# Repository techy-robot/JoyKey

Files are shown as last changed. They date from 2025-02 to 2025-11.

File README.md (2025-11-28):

---
modified: 2025-02-20T21:09:22-07:00
---
# JoyKey
This is a small macropad that simultaneously acts as game controller and an entertainment device. 

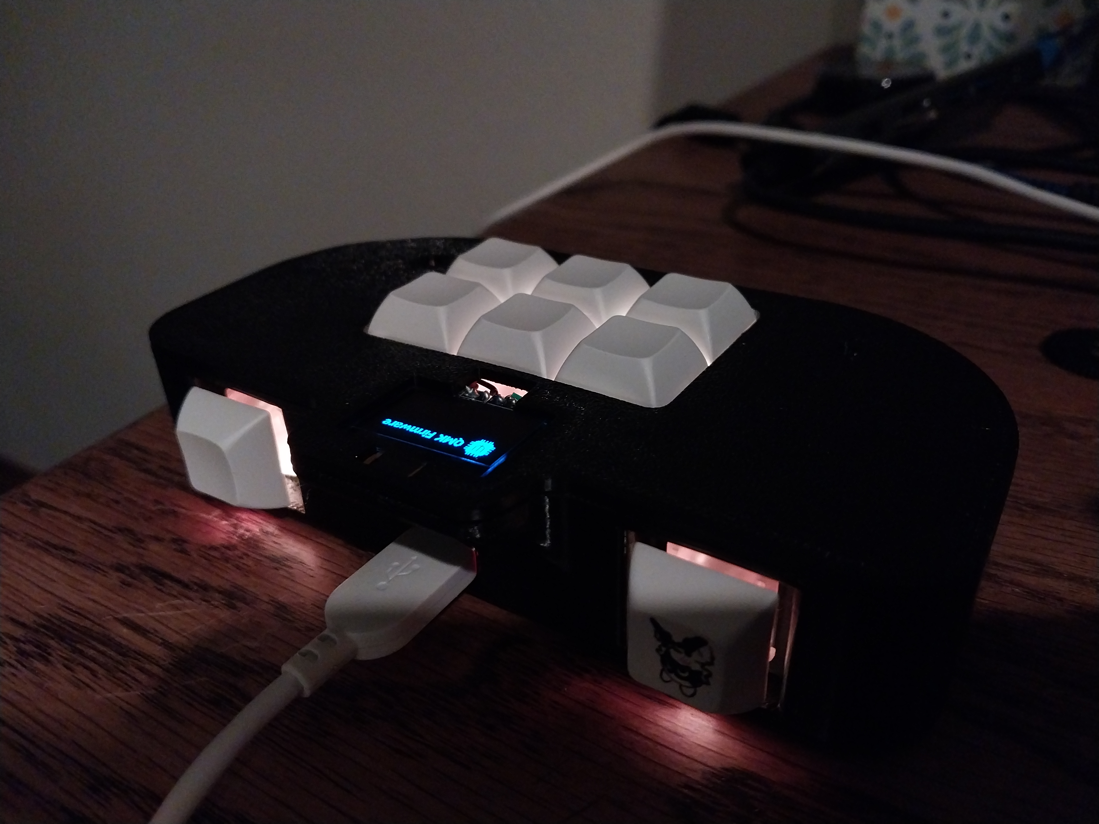
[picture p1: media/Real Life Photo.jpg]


The name is inspired by the Nintendo JoyCon portmanteau (Joystick Controller) except I have replaced the 2nd word with "Keypad" (Joystick Keypad). See [name ideas](name%20ideas.md) for other things I came up with.

My main repo were development will continue: https://github.com/techy-robot/JoyKey

# Features
- Customizable macro pad using QMK firmware
- Game controller mimicking a joy-con
- Offline games that can be played on the display with no connections
- Small handheld size
- Linear keys

# Approoved Parts BOM
- 8 Cherry mx Red keys with clear shell variant
- 8 Black keycaps
- 128x64 px SSD1306-based monochrome display near the top
- SEEED Xiao RP2040 (can be replaced later w/ SEEED xiao MG24 or nRF52840 Sense for BLE and other goodies)
- 12 Sk6812 Mini-E reverse mount RGB leds
- 3 M3x16 screws and M3 heatsets

# Extra Parts BOM
- 1 Analog PS2 Joystick (I already have)
- 1 Alps SRBE110301. (flat volume dial on the side). LCSC #C160861
- AP2112K-3.3 Linear Regulator. LCSC #C51118
- MCP73831T-2ACI/OT Lipo Battery Charger. LCSC #C424093
- 4 10uf 0805 capacitors. LCSC #C15850
- DMG3415 Sot23-3 PMOS. LCSC #C7202986
- 3 10k 0805 resistors. LCSC #C17414
- 1 2k 0805 resistor. LCSC #C17604
- 1 0603 LED. LCSC #C2286
- 1 LSM6DS3 LCSC #C967633
- JST PH S2B smd LCSC #C295747
- 12 1N4148W diodes LCSC #C2128
- 1 MBR0540 schotkey LCSC #C78545

# Pictures

## Case
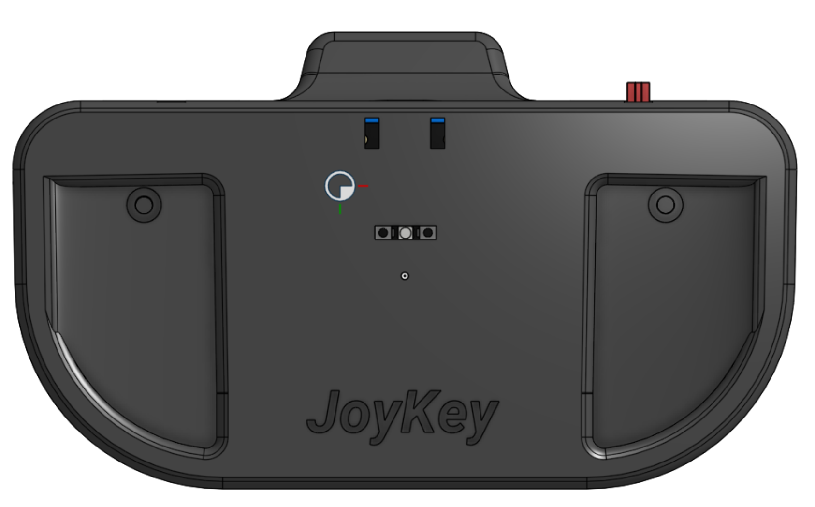
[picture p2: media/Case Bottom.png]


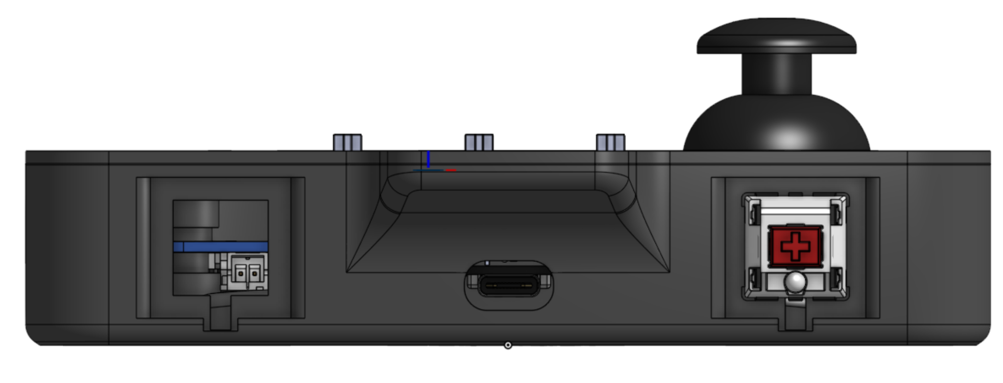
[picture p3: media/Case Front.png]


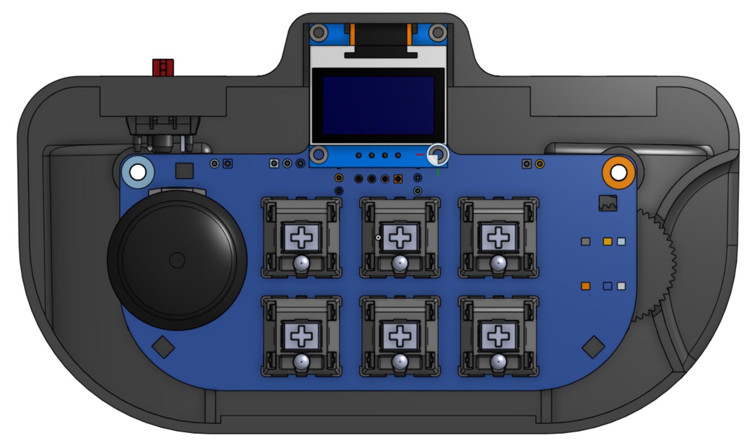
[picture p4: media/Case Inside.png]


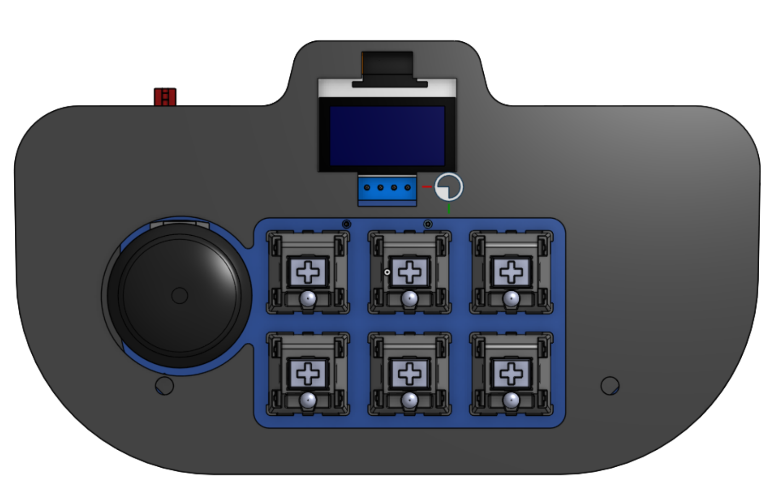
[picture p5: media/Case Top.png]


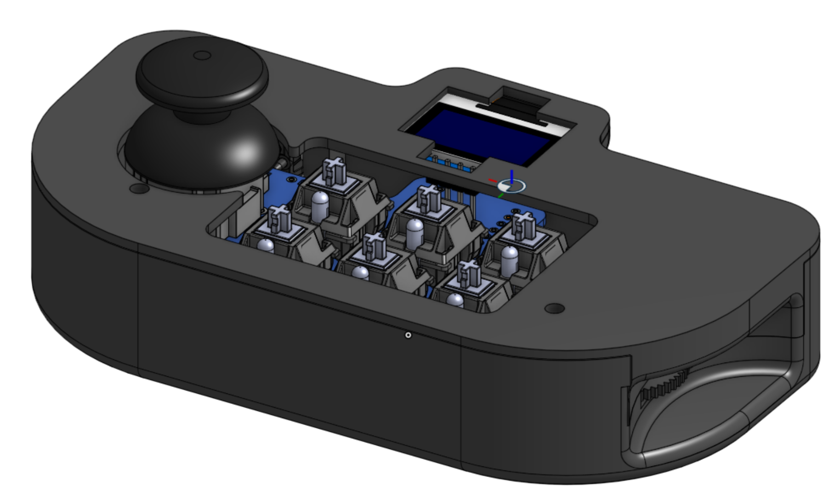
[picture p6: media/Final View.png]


## PCB
Bottom
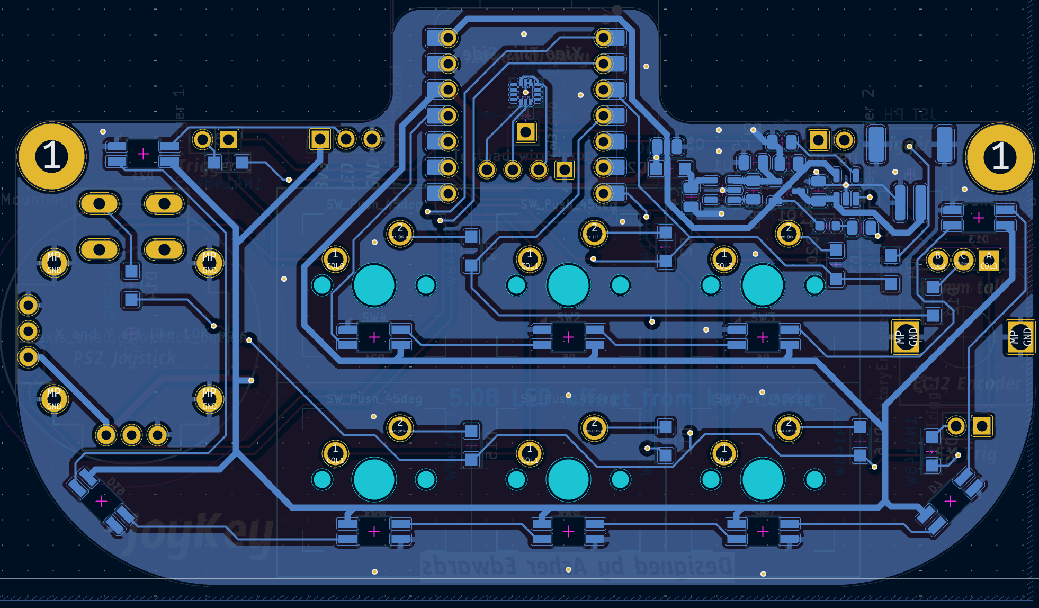
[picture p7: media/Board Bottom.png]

Top
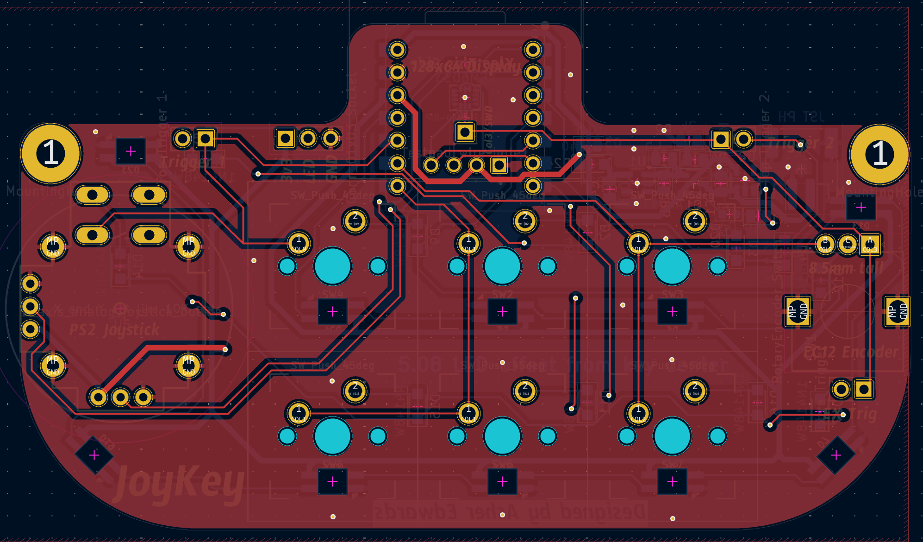
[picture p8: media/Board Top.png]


## Schematic
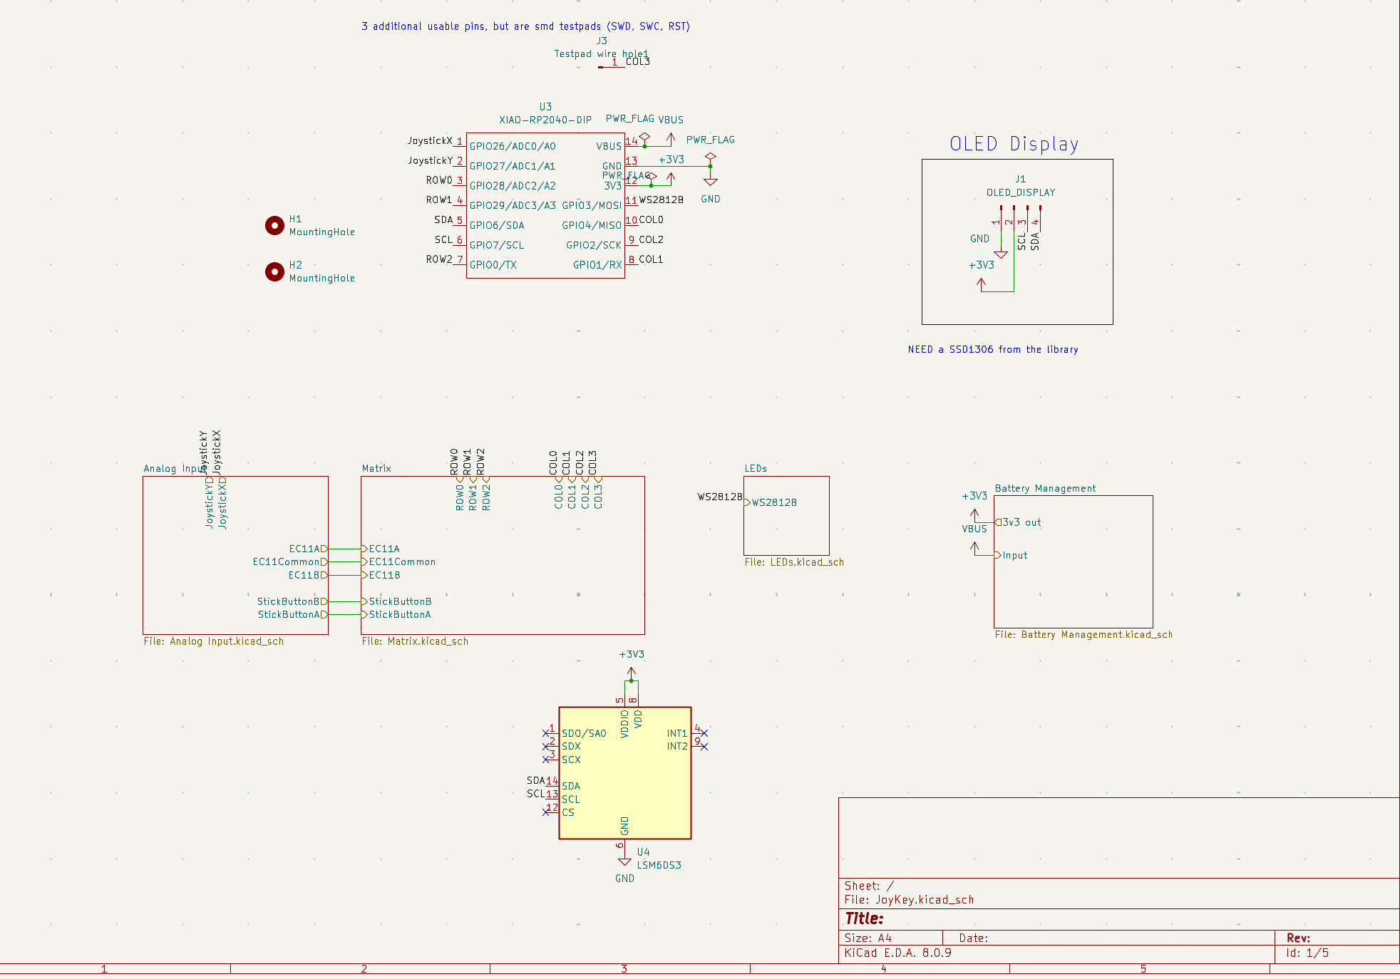
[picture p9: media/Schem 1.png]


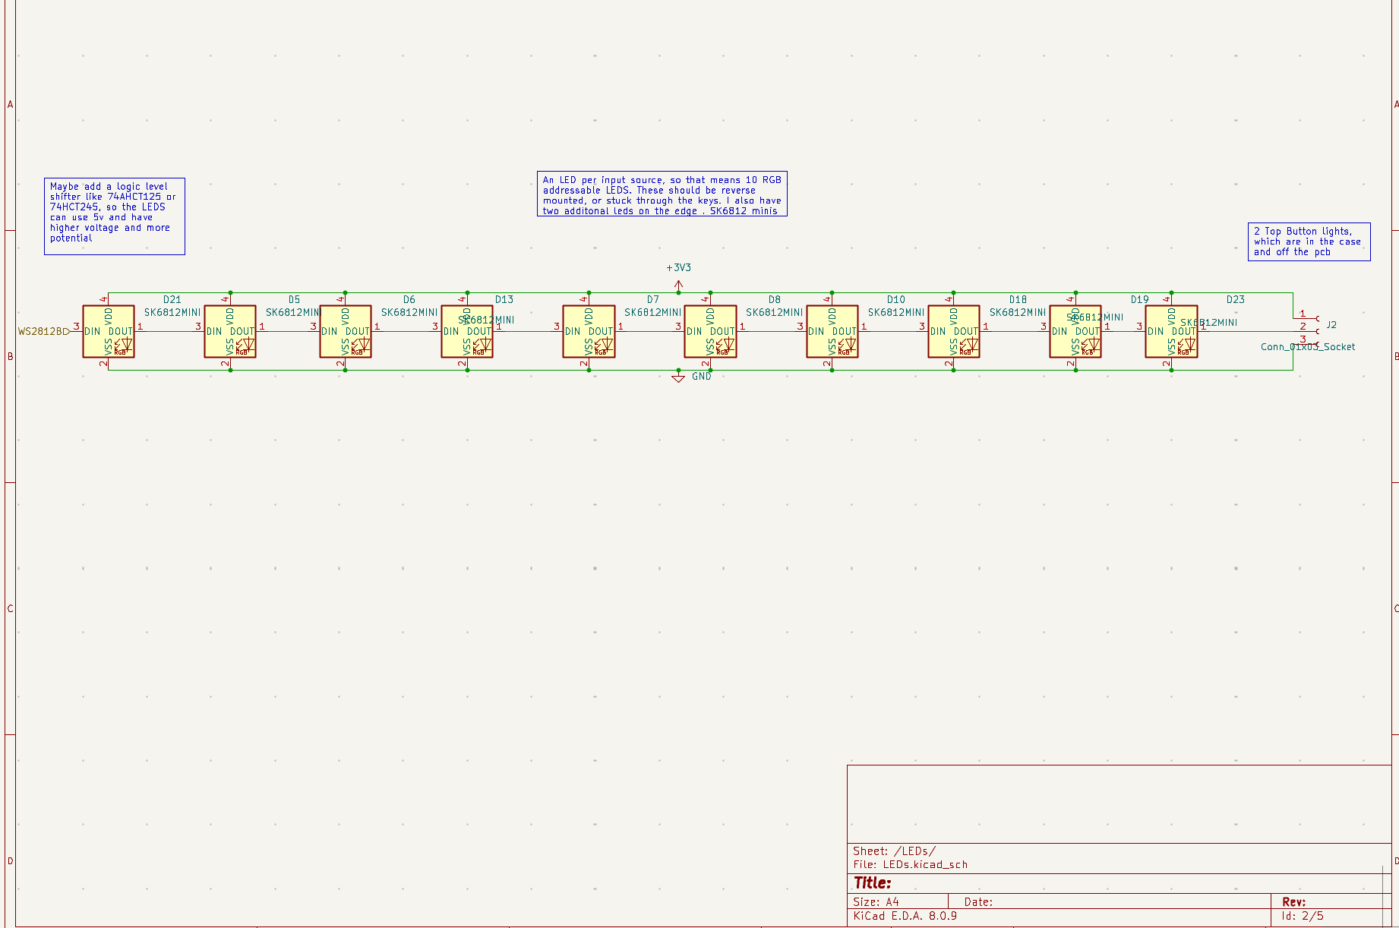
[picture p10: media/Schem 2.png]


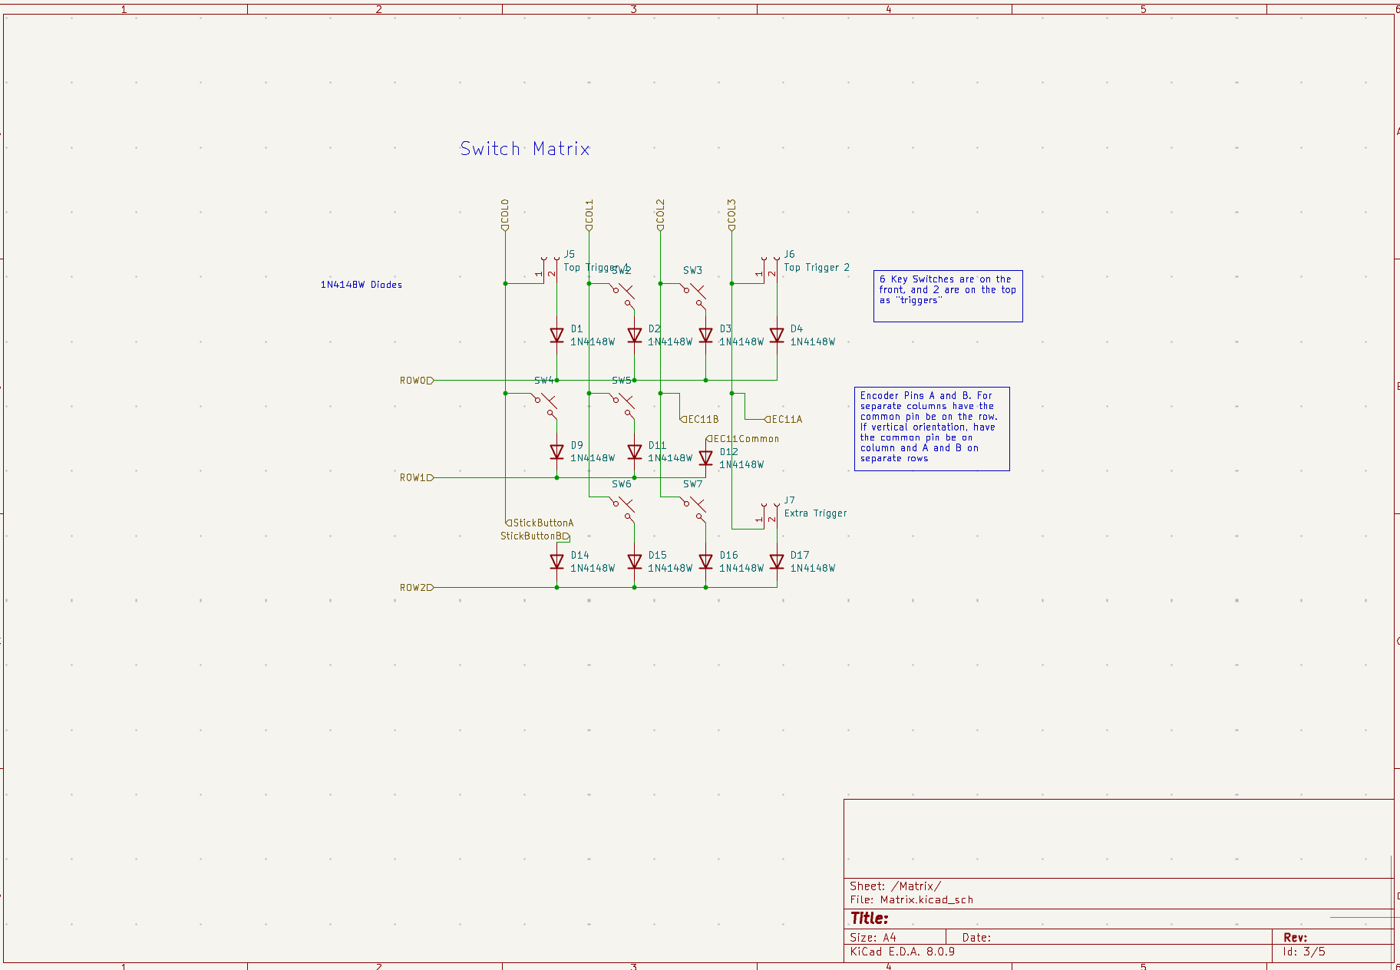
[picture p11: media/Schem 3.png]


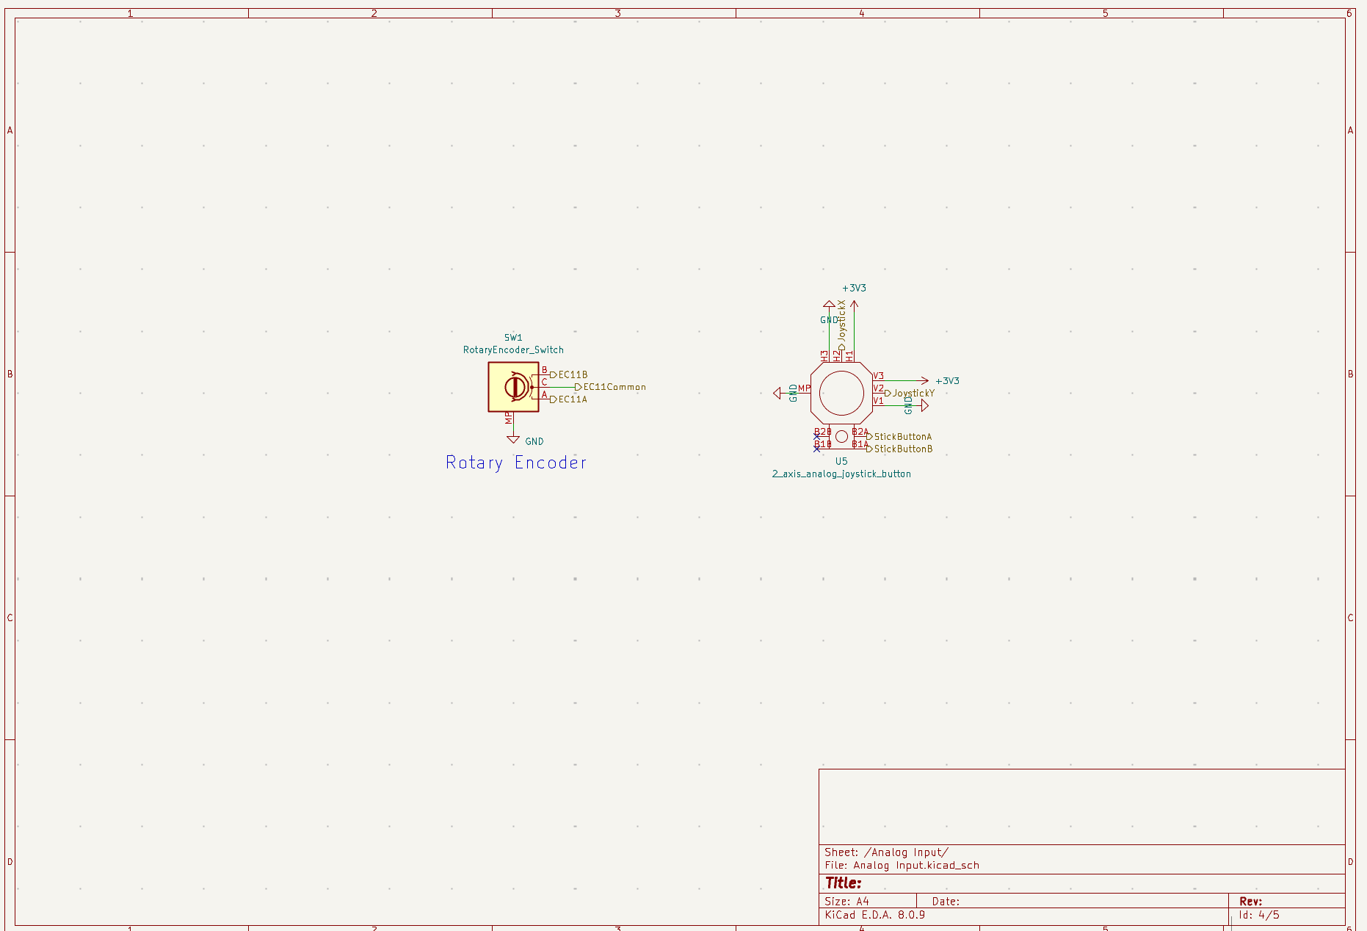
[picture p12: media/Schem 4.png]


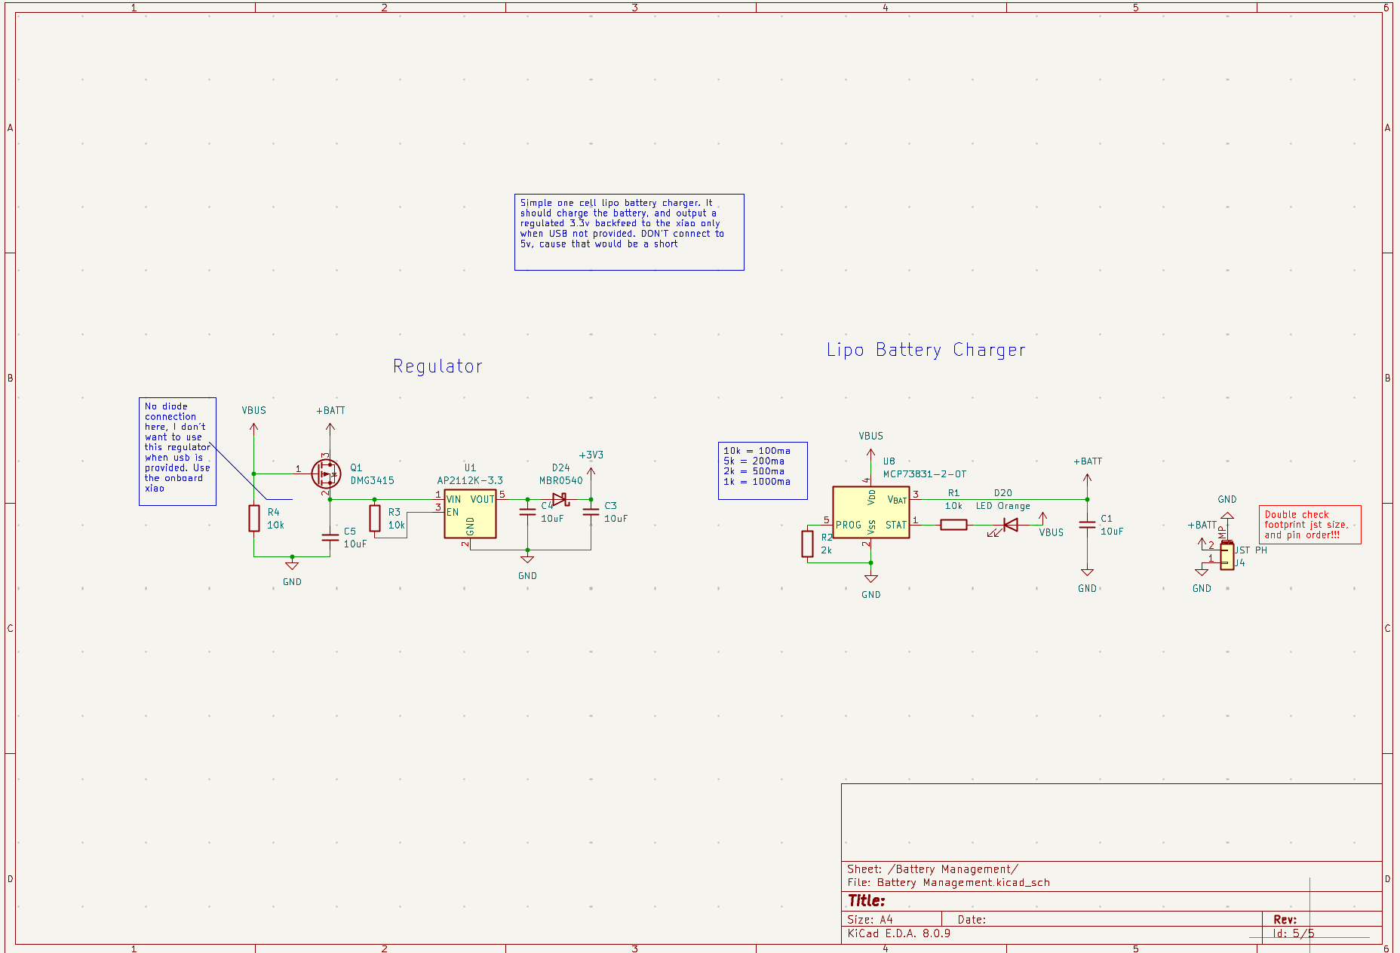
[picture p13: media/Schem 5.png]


# Sprite Credit

All icons that are converted using qmk's command line tool were originally from Nikoichu's 1-bit Pixel Icons set, which is licensed CC0 1.0

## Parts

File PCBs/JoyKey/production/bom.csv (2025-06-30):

Designator | Footprint | Quantity | Value | LCSC Part #
C1, C10, C11, C12, C13, C14, C2, C3, C4, C5, C6, C7, C8, C9 | 0805 | 14 | 10uF | C15850
D1, D11, D12, D14, D15, D16, D17, D2, D22, D3, D4, D9 | Nexperia_CFP3_SOD-123W | 12 | 1N4148W | C2128
D10, D13, D18, D19, D21, D23, D5, D6, D7, D8 | SK6812MINI-E | 10 | SK6812MINI
D20 | 0603 | 1 | LED Orange | C2286
D24 | Nexperia_CFP3_SOD-123W | 1 | MBR0540 | C78545
J1 | SSD1306-OLED096-128x64 | 1 | OLED_DISPLAY
J2 | PinHeader_1x03_P2.54mm_Vertical | 1 | Conn_01x03_Socket
J3 | PinHeader_1x01_P2.54mm_Vertical | 1 | Testpad wire hole1
J4 | JST_PH_S2B-PH-SM4-TB_1x02-1MP_P2.00mm_Horizontal | 1 | JST PH | C295747
J5 | PinHeader_1x02_P2.54mm_Vertical | 1 | Top Trigger 1
J6 | PinHeader_1x02_P2.54mm_Vertical | 1 | Top Trigger 2
Q1 | SOT-23-3 | 1 | DMG3415 | C7202986
R1, R3, R4 | 0805 | 3 | 10k | C17414
R2 | 0805 | 1 | 2k | C17604
SW2, SW3, SW4, SW5, SW6, SW7 | MX-Solderable-1U | 6 | SW_Push_45deg
U1 | SOT-23-5 | 1 | AP2112K-3.3 | C51118
U3 | XIAO-RP2040-DIP | 1 | XIAO-RP2040-DIP
U4 | LGA-14_3x2.5mm_P0.5mm_LayoutBorder3x4y_COSTSAVERPADs | 1 | LSM6DS3 | C967633
U5 | Adafruit 2-Axis joystick | 1 | 2_axis_analog_joystick_button
U6 | Alps SRBE110301 | 1 | Alps SRBE110301
U8 | SOT-23-5 | 1 | MCP73831-2-OT | C424093

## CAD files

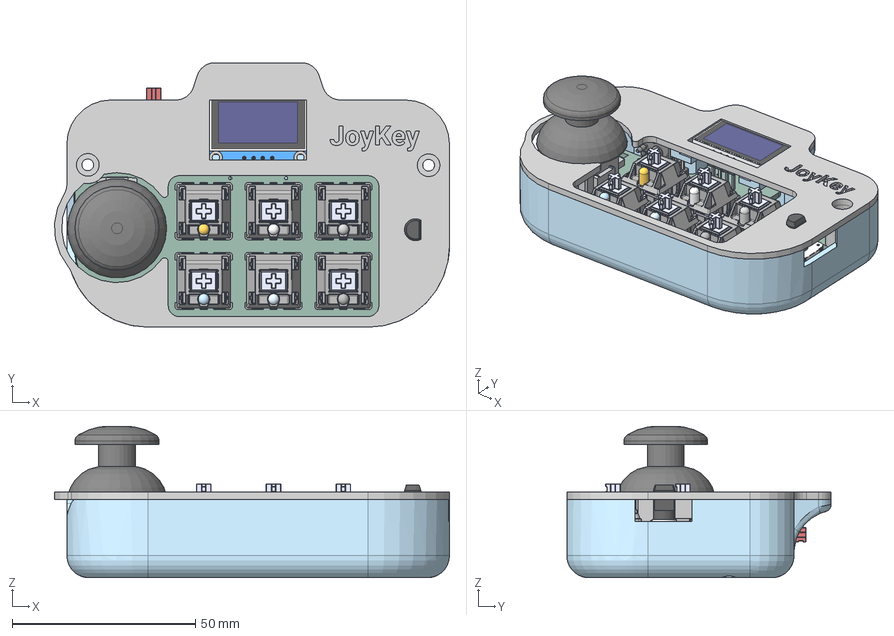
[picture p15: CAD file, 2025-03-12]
CAD/Main Assembly.step
107.8 x 72.2 x 41.3 mm
User Library-128x64I2COLEDDisplayAdafruit x 4
JoyKey Case
Pin2
Top
Bottom
Led 3mm_trans x 2
Pin1
Pulsador
Pieza5^Cherry MX
JoyKey lid
CQ assembly_8 x 4
MX ����_��_��1 _4 x 10
MX ����_��_��1 _3 x 10
MX ����_��_��1 _2 x 10
joystick base
MX ����_��_��1 _5 x 10
CQ assembly_2 x 4
MX ����_��_��1 _1 x 10
CQ assembly_4 x 4
CQ assembly_6 x 4
MX ����_��_��1 x 10
CQ assembly_7 x 4
CQ assembly x 4
CQ assembly_9 x 4
CQ assembly_5 x 4
CQ assembly_10 x 4
joystick cap
random knob
CQ assembly_1 x 4
PinHeader_1x02_P254mm_Vertical
CQ assembly_3 x 4
_autosave-JoyKey_PCB
EC12 Encoder 10mm 3pin.stp<1>[1]
EC12 Encoder 10mm 3pin.stp<1>[3]
EC12 Encoder 10mm 3pin.stp<1>[2]
EC12 Encoder 10mm 3pin.stp<1>[4]
EC12 Encoder 10mm 3pin.stp<1>[5]
PinHeader_1x03_P254mm_Vertical
PinHeader_1x02_P254mm_Vertical_1
main x 16
type-c v2 x 24
smd_button v3(Mirror)
VDD
DOUT
DIN
VSS
smd_button v3

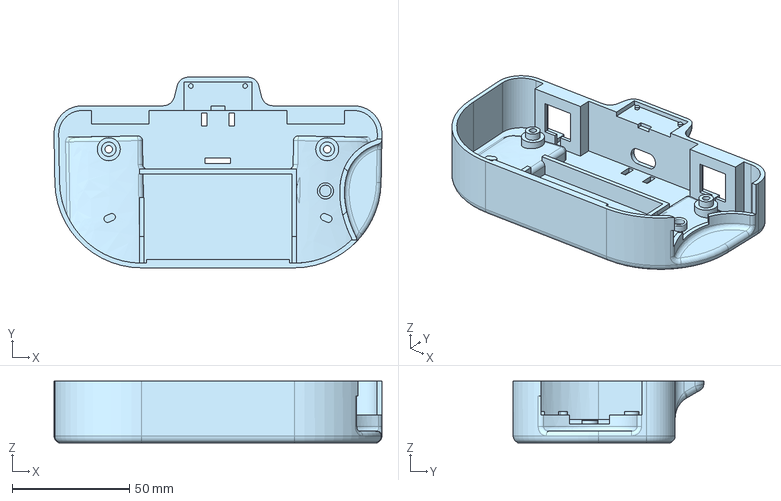
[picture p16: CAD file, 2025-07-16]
CAD/Case/Case - JoyKey Case.step
139.6 x 81.2 x 26.2 mm

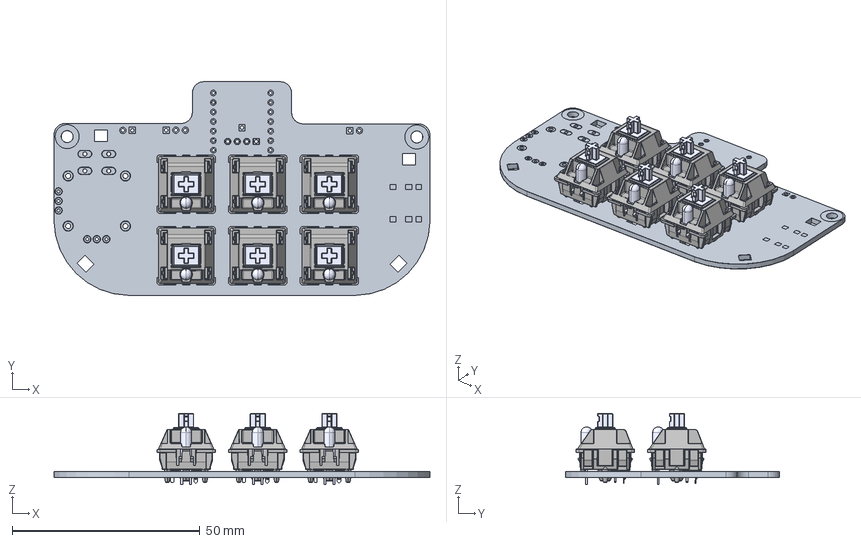
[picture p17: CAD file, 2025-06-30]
CAD/JoyKey_pcb.step
100.0 x 56.8 x 18.9 mm
MX Öá °´¼ü¡ä_¨¹___¡§1 x 6
MX ס סͥ¨¢¨¬_¡§¡顧__ x 6
MXס ϞñLEDLEDLED x 6
MXÖá ÖáÌå µ×²¿ ¦Ì¡Á2__Ä¬ÈÏ_¨¢2____¨¨_ x 6
֫½ğ__Ĭɏ__¨¨_ x 6
JoyKey_pad
JoyKey_soldermask
JoyKey_PCB

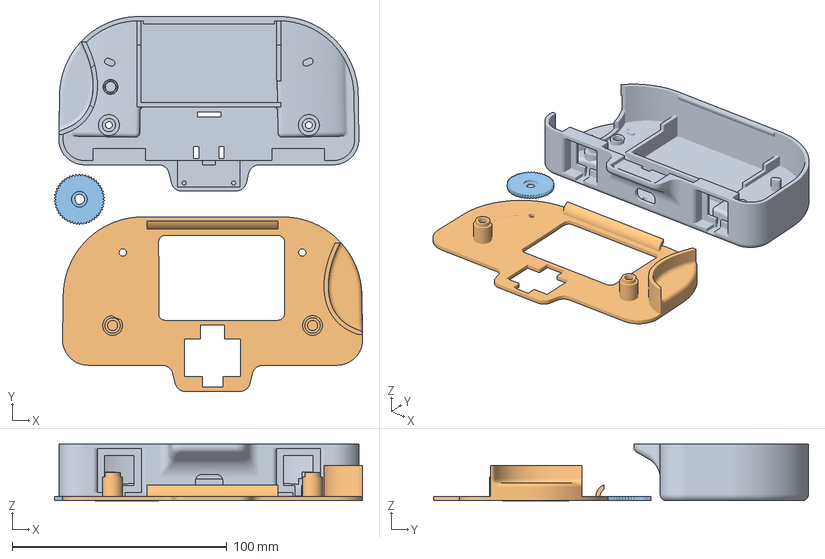
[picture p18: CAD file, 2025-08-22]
Print files no joystick.3mf
143.4 x 174.4 x 26.3 mm
Case - JoyKey Case.step
Case - JoyKey lid.step
Case - Dial.step

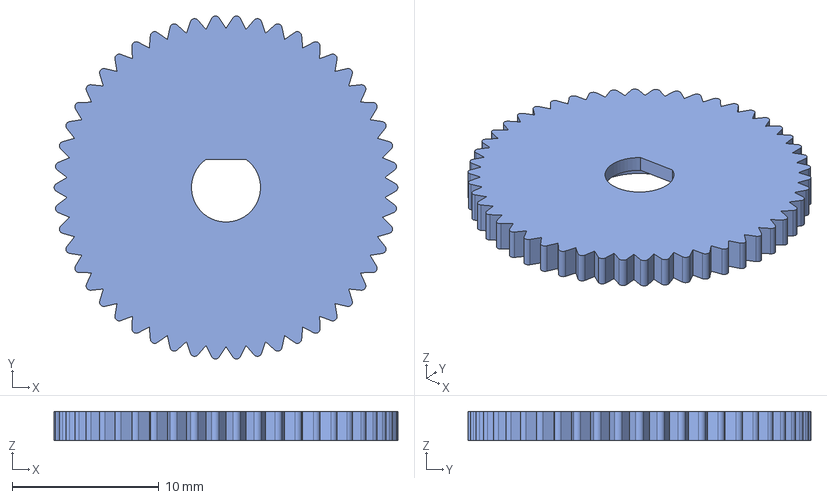
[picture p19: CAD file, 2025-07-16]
CAD/Case/Case - Dial.step
23.4 x 23.4 x 2.00 mm

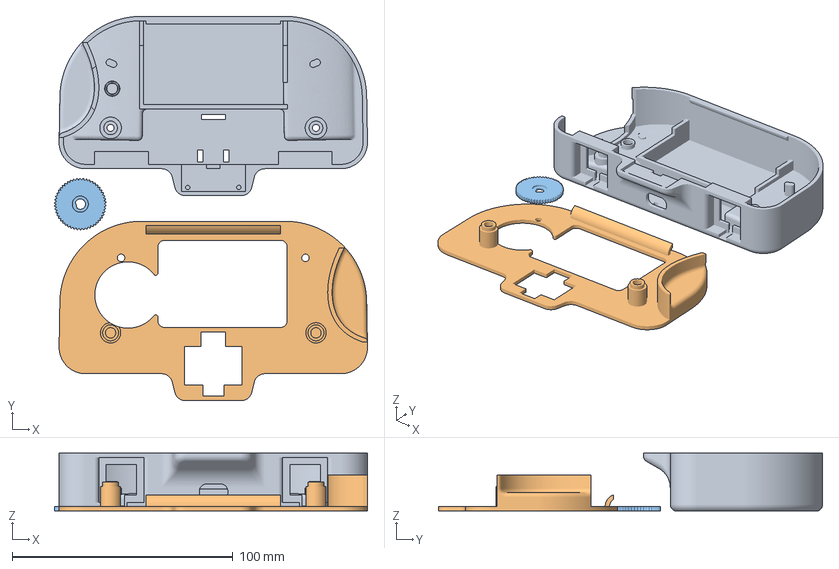
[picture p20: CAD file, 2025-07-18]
Print files.3mf
141.7 x 174.0 x 26.3 mm
Case - JoyKey Case.step
Case - JoyKey lid.step
Case - Dial.step

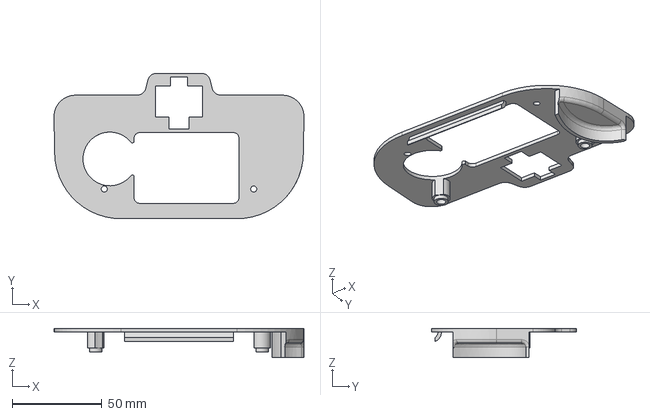
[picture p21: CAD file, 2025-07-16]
CAD/Case/Case - JoyKey lid.step
139.6 x 81.2 x 16.3 mm

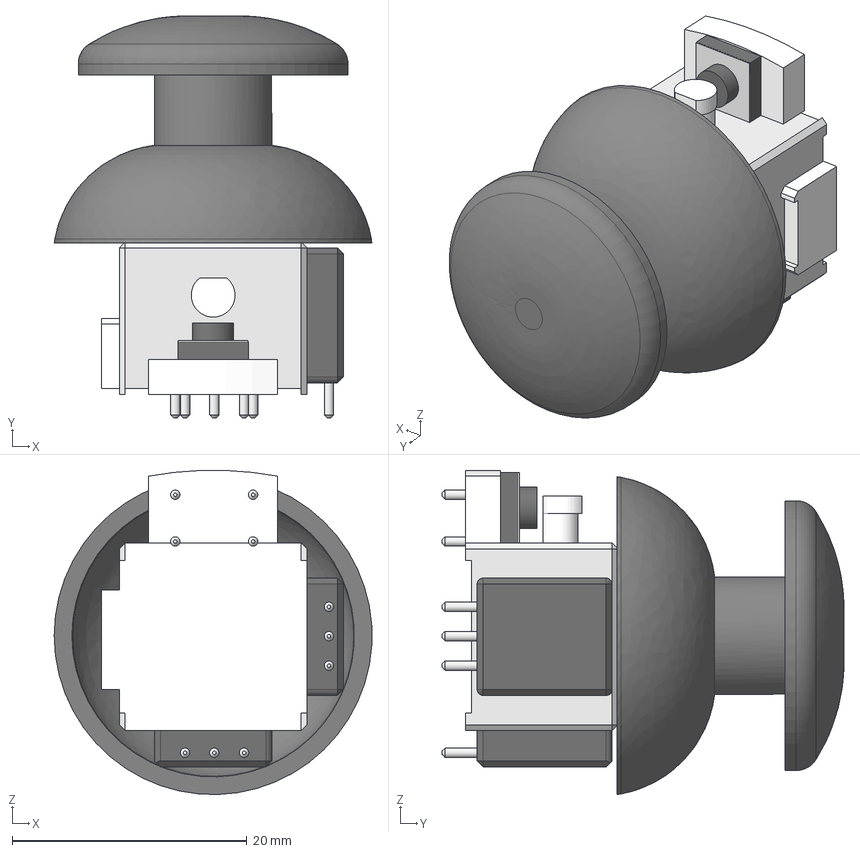
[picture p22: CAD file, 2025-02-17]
CAD/PS2 Joystick.step
27.1 x 34.3 x 27.6 mm

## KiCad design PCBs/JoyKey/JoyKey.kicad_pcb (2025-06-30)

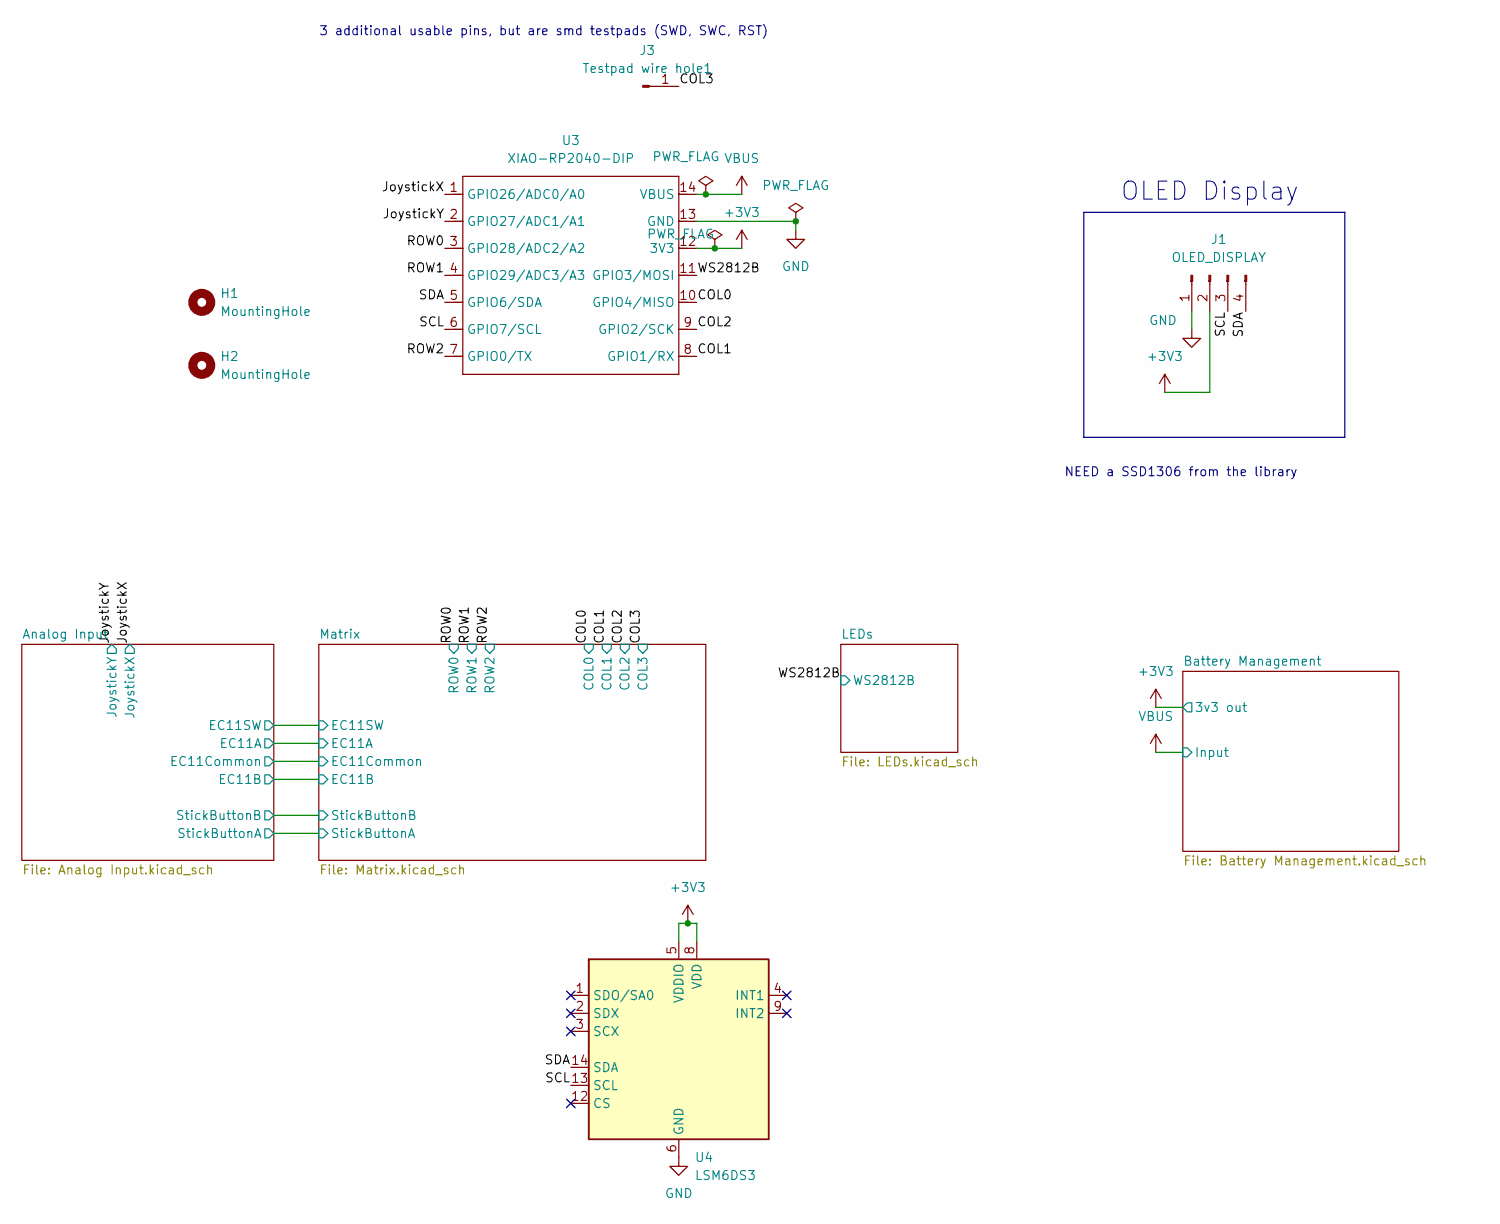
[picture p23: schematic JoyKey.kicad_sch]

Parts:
H1, H2: MountingHole; MountingHole_3.2mm_M3_Pad
J1: OLED_DISPLAY; SSD1306-OLED096-128x64
J3: Testpad wire hole1; PinHeader_1x01_P2.54mm_Vertical
U3: XIAO-RP2040-DIP
U4: LSM6DS3; LGA-14_3x2.5mm_P0.5mm_LayoutBorder3x4y_COSTSAVERPADs; LCSC C967633

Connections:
+3V3: J1.2, U3.12 (3V3), U4.5 (VDDIO), U4.8 (VDD); also elsewhere on the board
/COL0: U3.10 (GPIO4/MISO); also elsewhere on the board
/COL1: U3.8 (GPIO1/RX); also elsewhere on the board
/COL2: U3.9 (GPIO2/SCK); also elsewhere on the board
/COL3: J3.1; also elsewhere on the board
/JoystickX: U3.1 (GPIO26/ADC0/A0); also elsewhere on the board
/JoystickY: U3.2 (GPIO27/ADC1/A1); also elsewhere on the board
/ROW0: U3.3 (GPIO28/ADC2/A2); also elsewhere on the board
/ROW1: U3.4 (GPIO29/ADC3/A3); also elsewhere on the board
/ROW2: U3.7 (GPIO0/TX); also elsewhere on the board
/SCL: J1.3, U3.6 (GPIO7/SCL), U4.13 (SCL)
/SDA: J1.4, U3.5 (GPIO6/SDA), U4.14 (SDA)
/WS2812B: U3.11 (GPIO3/MOSI); also elsewhere on the board
GND: J1.1, U3.13 (GND), U4.6 (GND), U4.7 (GND); also elsewhere on the board
VBUS: U3.14 (VBUS); also elsewhere on the board

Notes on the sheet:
NEED a SSD1306 from the library
OLED Display
3 additional usable pins, but are smd testpads (SWD, SWC, RST)

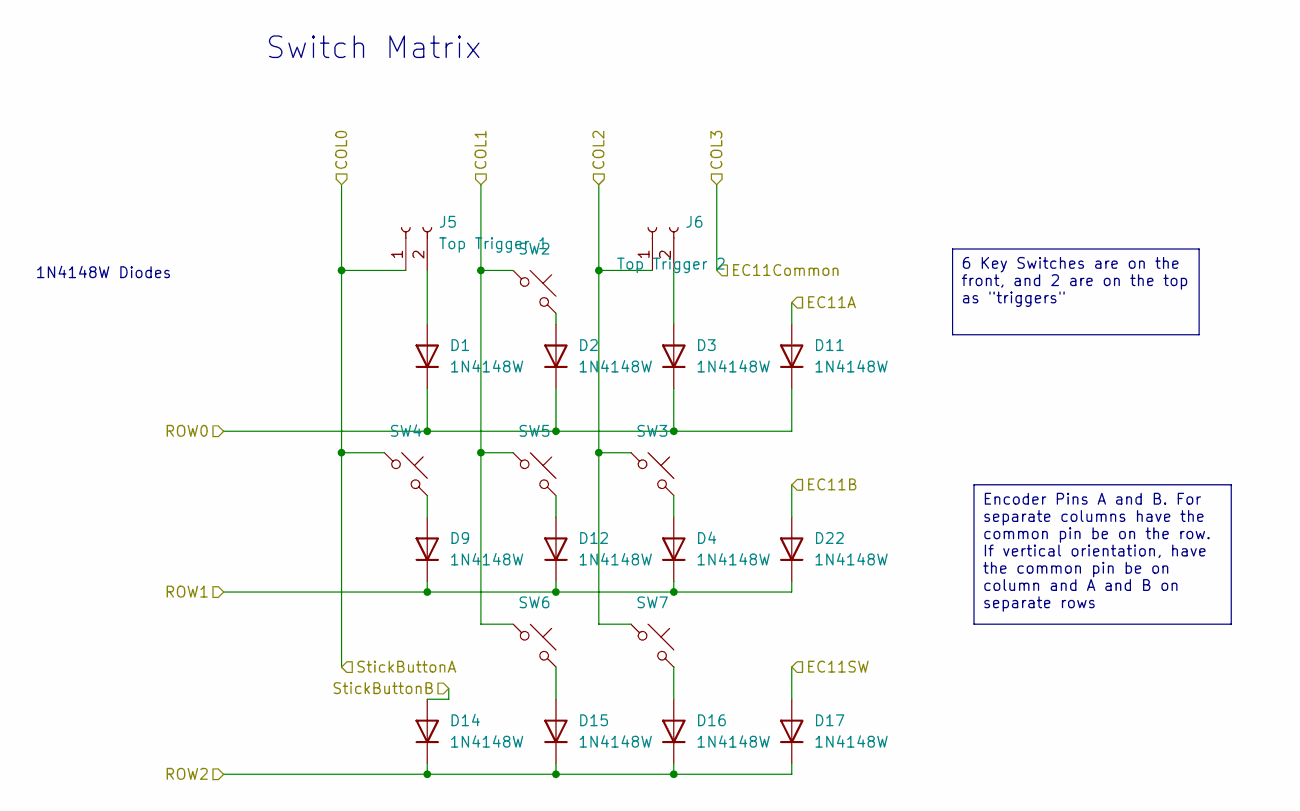
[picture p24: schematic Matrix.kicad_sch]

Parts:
D1, D2, D3, D4, D9, D11, D12, D14, D15, D16, D17, D22: 1N4148W; Nexperia_CFP3_SOD-123W; LCSC C2128
J5: Top Trigger 1; PinHeader_1x02_P2.54mm_Vertical
J6: Top Trigger 2; PinHeader_1x02_P2.54mm_Vertical
SW2, SW3, SW4, SW5, SW6, SW7: SW_Push_45deg; MX-Solderable-1U

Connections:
/Analog Input/EC11A: D11.2 (A); also elsewhere on the board
/Analog Input/EC11B: D22.2 (A); also elsewhere on the board
/Analog Input/EC11SW: D17.2 (A); also elsewhere on the board
/Analog Input/StickButtonB: D14.2 (A); also elsewhere on the board
/COL0: J5.1, SW4.1; also elsewhere on the board
/COL1: SW2.1, SW5.1, SW6.1; also elsewhere on the board
/COL2: J6.1, SW3.1, SW7.1; also elsewhere on the board
/ROW0: D1.1 (K), D2.1 (K), D3.1 (K), D11.1 (K); also elsewhere on the board
/ROW1: D4.1 (K), D9.1 (K), D12.1 (K), D22.1 (K); also elsewhere on the board
/ROW2: D14.1 (K), D15.1 (K), D16.1 (K), D17.1 (K); also elsewhere on the board
unnamed: D1.2 (A), J5.2
unnamed: D2.2 (A), SW2.2
unnamed: D3.2 (A), J6.2
unnamed: D4.2 (A), SW3.2
unnamed: D9.2 (A), SW4.2
unnamed: D12.2 (A), SW5.2
unnamed: D15.2 (A), SW6.2
unnamed: D16.2 (A), SW7.2

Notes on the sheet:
Switch Matrix
1N4148W Diodes
Encoder Pins A and B. For separate columns have the common pin be on the row. If vertical orientation, have the common pin be on column and A and B on separate rows
6 Key Switches are on the front, and 2 are on the top as "triggers"

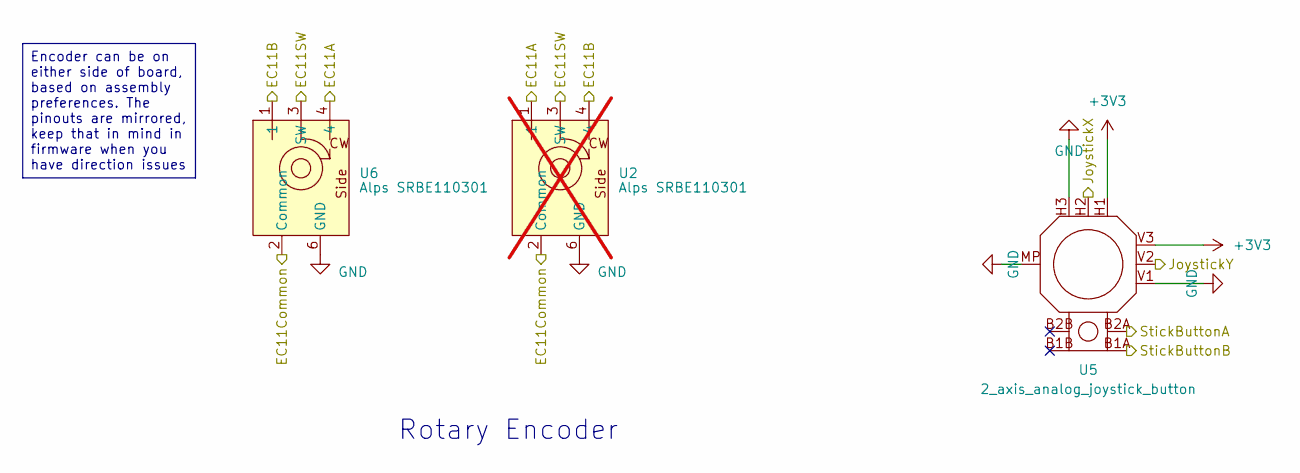
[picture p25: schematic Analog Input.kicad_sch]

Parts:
U2: Alps SRBE110301; not fitted
U5: 2_axis_analog_joystick_button; Adafruit 2-Axis joystick
U6: Alps SRBE110301

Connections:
+3V3: U5.H1, U5.V3; also elsewhere on the board
/Analog Input/EC11A: U2.1, U6.4; also elsewhere on the board
/Analog Input/EC11B: U2.4, U6.1; also elsewhere on the board
/Analog Input/EC11SW: U2.3 (SW), U6.3 (SW); also elsewhere on the board
/Analog Input/StickButtonB: U5.B1A; also elsewhere on the board
/COL0: U5.B2A; also elsewhere on the board
/COL3: U2.2 (Common), U6.2 (Common); also elsewhere on the board
/JoystickX: U5.H2; also elsewhere on the board
/JoystickY: U5.V2; also elsewhere on the board
GND: U2.5 (GND), U2.6 (GND), U5.H3, U5.MP, U5.V1, U6.5 (GND), U6.6 (GND); also elsewhere on the board

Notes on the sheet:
Rotary Encoder
Encoder can be on either side of board, based on assembly preferences. The pinouts are mirrored, keep that in mind in firmware when you have direction issues

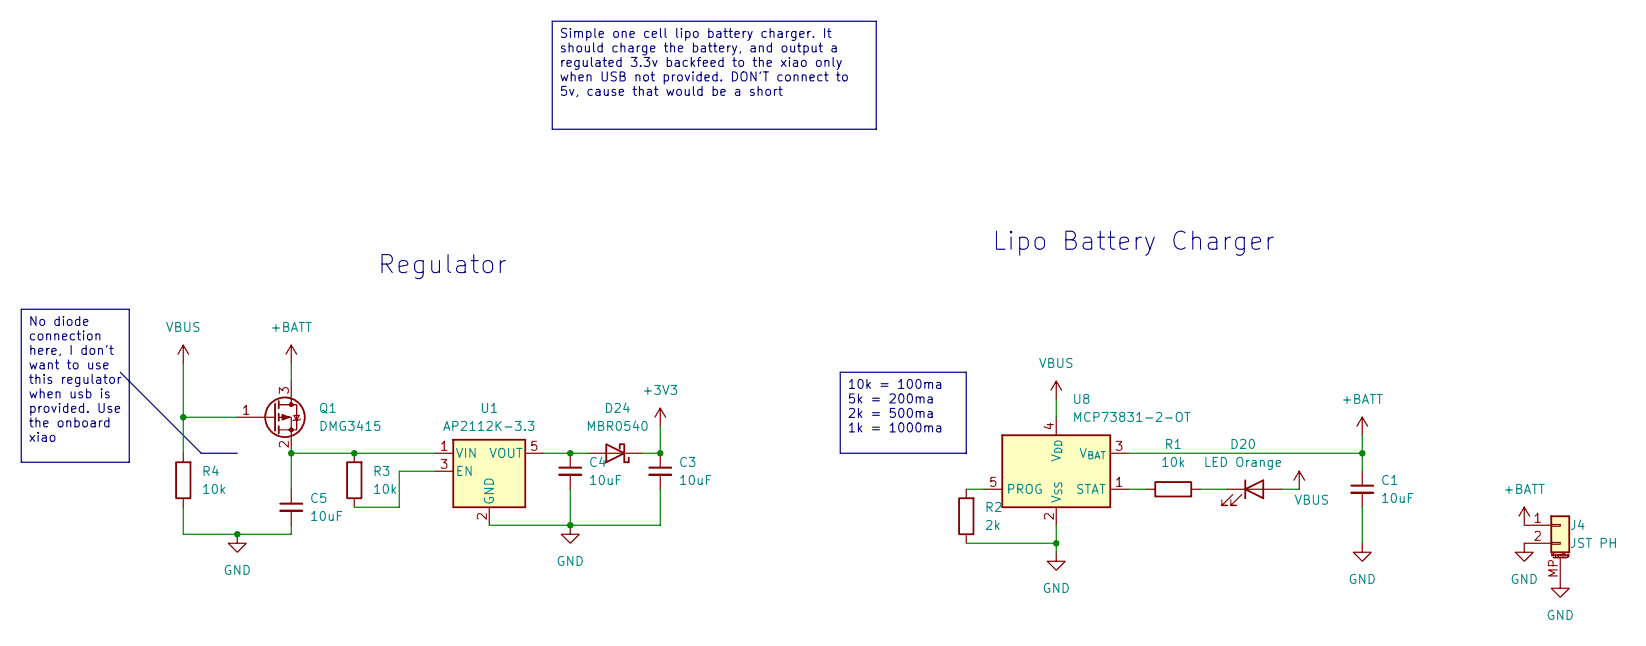
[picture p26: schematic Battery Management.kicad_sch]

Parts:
C1, C3, C4, C5: 10uF; C_0805_2012Metric; LCSC C15850
D20: LED Orange; LED_0603_1608Metric; LCSC C2286
D24: MBR0540; Nexperia_CFP3_SOD-123W; LCSC C78545
J4: JST PH; JST_PH_S2B-PH-SM4-TB_1x02-1MP_P2.00mm_Horizontal; LCSC C295747
Q1: DMG3415; SOT-23-3; LCSC C7202986
R1, R3, R4: 10k; R_0805_2012Metric; LCSC C17414
R2: 2k; R_0805_2012Metric; LCSC C17604
U1: AP2112K-3.3; SOT-23-5; LCSC C51118
U8: MCP73831-2-OT; SOT-23-5; LCSC C424093

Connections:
+3V3: C3.1, D24.1 (K); also elsewhere on the board
+BATT: C1.1, J4.1, Q1.3 (D), U8.3 (V_{BAT})
GND: C1.2, C3.2, C4.2, C5.2, J4.2, J4.MP (MountPin), R2.1, R4.1, U1.2 (GND), U8.2 (V_{SS}); also elsewhere on the board
unnamed: D20.1 (K), R1.2
unnamed: C4.1, D24.2 (A), U1.5 (VOUT)
unnamed: C5.1, Q1.2 (S), R3.2, U1.1 (VIN)
unnamed: R3.1, U1.3 (EN)
unnamed: R2.2, U8.5 (PROG)
unnamed: R1.1, U8.1 (STAT)
VBUS: D20.2 (A), Q1.1 (G), R4.2, U8.4 (V_{DD}); also elsewhere on the board

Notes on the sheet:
Lipo Battery Charger
Regulator
10k = 100ma 5k = 200ma 2k = 500ma 1k = 1000ma
No diode connection here, I don't want to use this regulator when usb is provided. Use the onboard xiao
Simple one cell lipo battery charger. It should charge the battery, and output a regulated 3.3v backfeed to the xiao only when USB not provided. DON'T connect to 5v, cause that would be a short

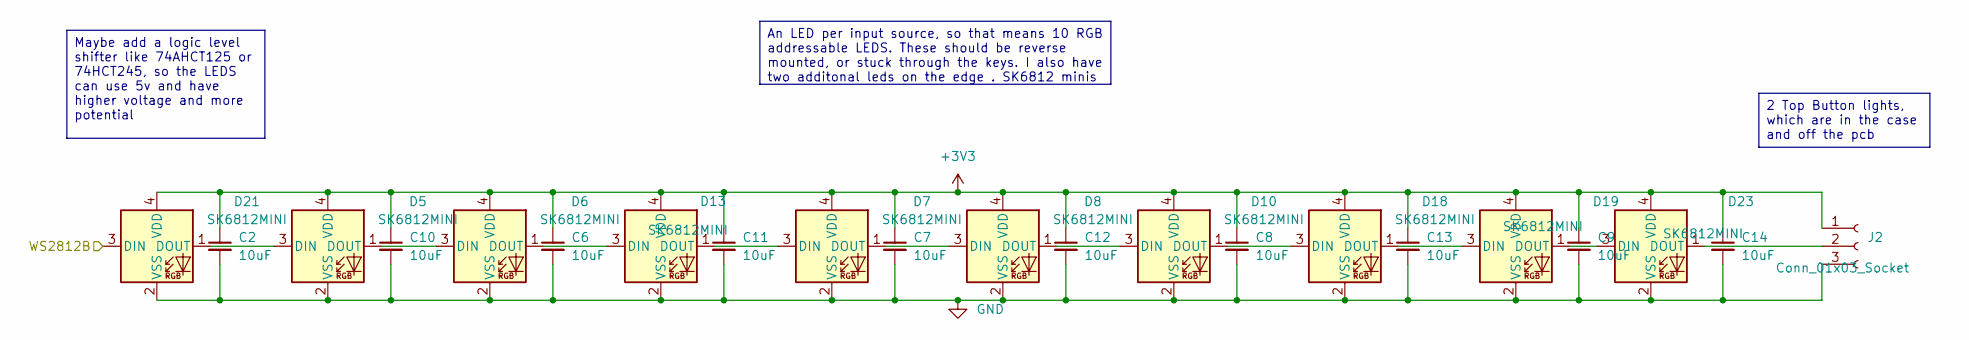
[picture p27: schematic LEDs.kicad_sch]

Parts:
C2, C6, C7, C8, C9, C10, C11, C12, C13, C14: 10uF; C_0805_2012Metric; LCSC C15850
D5, D6, D7, D8, D10, D13, D18, D19, D21, D23: SK6812MINI; SK6812MINI-E
J2: Conn_01x03_Socket; PinHeader_1x03_P2.54mm_Vertical

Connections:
+3V3: C2.1, C6.1, C7.1, C8.1, C9.1, C10.1, C11.1, C12.1, C13.1, C14.1, D5.4 (VDD), D6.4 (VDD), D7.4 (VDD), D8.4 (VDD), D10.4 (VDD), D13.4 (VDD), D18.4 (VDD), D19.4 (VDD), D21.4 (VDD), D23.4 (VDD), J2.1; also elsewhere on the board
/WS2812B: D21.3 (DIN); also elsewhere on the board
GND: C2.2, C6.2, C7.2, C8.2, C9.2, C10.2, C11.2, C12.2, C13.2, C14.2, D5.2 (VSS), D6.2 (VSS), D7.2 (VSS), D8.2 (VSS), D10.2 (VSS), D13.2 (VSS), D18.2 (VSS), D19.2 (VSS), D21.2 (VSS), D23.2 (VSS), J2.3; also elsewhere on the board
unnamed: D5.1 (DOUT), D6.3 (DIN)
unnamed: D7.1 (DOUT), D8.3 (DIN)
unnamed: D8.1 (DOUT), D10.3 (DIN)
unnamed: D10.1 (DOUT), D18.3 (DIN)
unnamed: D6.1 (DOUT), D13.3 (DIN)
unnamed: D7.3 (DIN), D13.1 (DOUT)
unnamed: D18.1 (DOUT), D19.3 (DIN)
unnamed: D19.1 (DOUT), D23.3 (DIN)
unnamed: D5.3 (DIN), D21.1 (DOUT)
unnamed: D23.1 (DOUT), J2.2

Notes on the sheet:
2 Top Button lights, which are in the case and off the pcb
An LED per input source, so that means 10 RGB addressable LEDS. These should be reverse mounted, or stuck through the keys. I also have two additonal leds on the edge . SK6812 minis
Maybe add a logic level shifter like 74AHCT125 or 74HCT245, so the LEDS can use 5v and have higher voltage and more potential

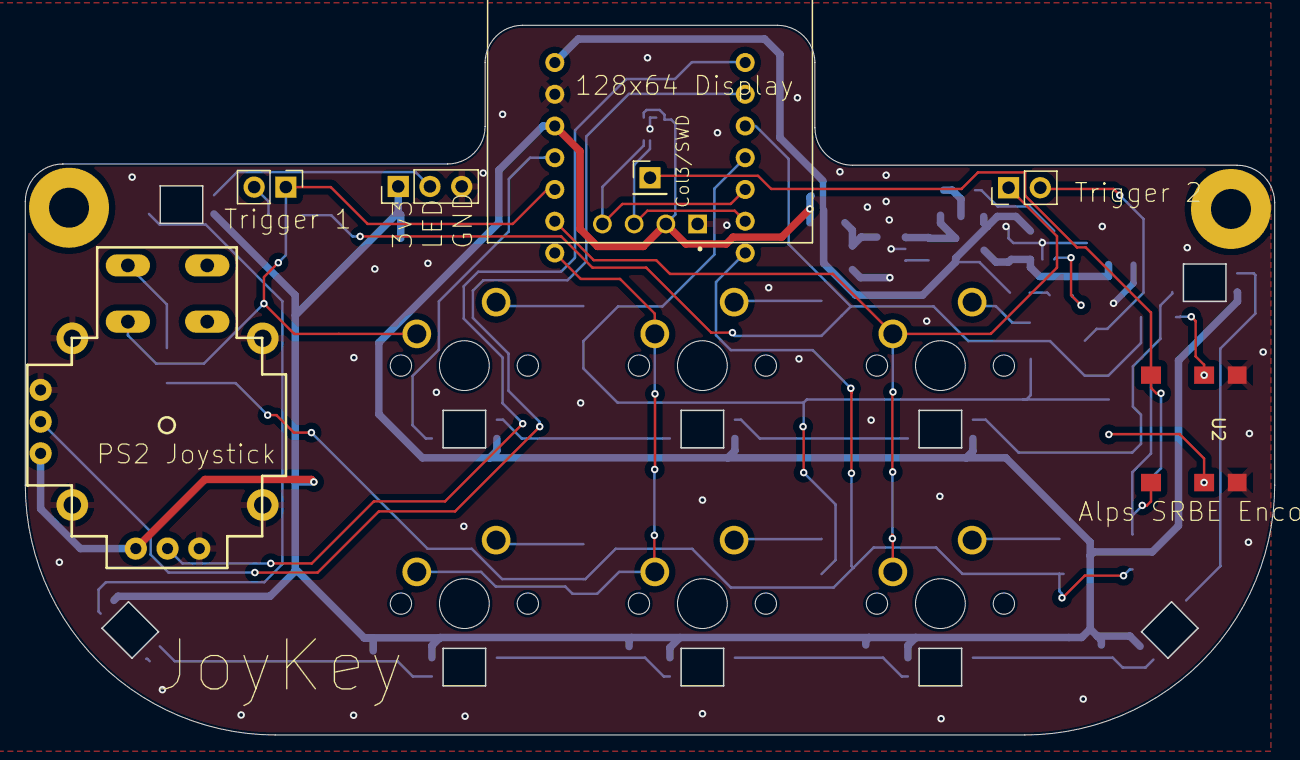
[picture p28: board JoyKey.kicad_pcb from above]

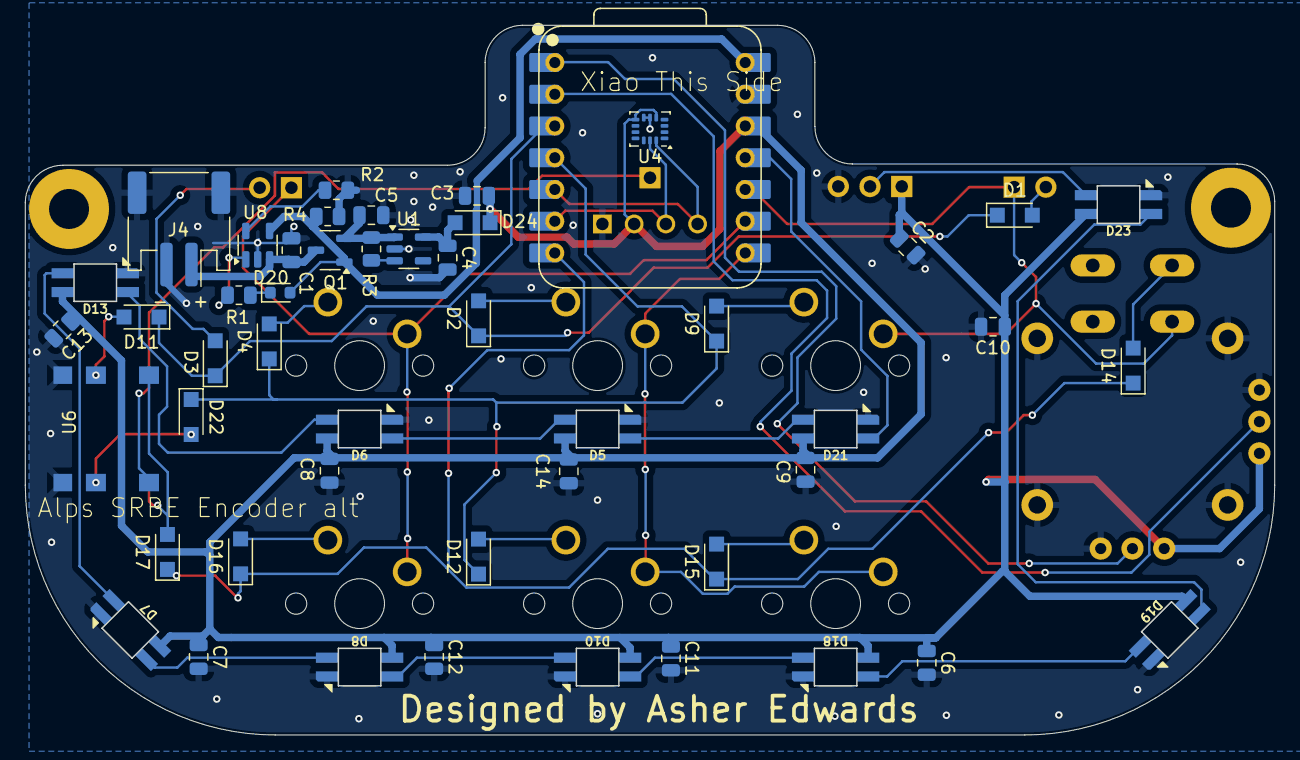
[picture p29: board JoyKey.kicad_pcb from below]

Board: 2 copper layers, 100.0 x 56.8 mm, 64 parts (49 on the bottom side), 44 nets.

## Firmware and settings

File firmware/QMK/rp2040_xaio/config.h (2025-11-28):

/*
Copyright 2025 Asher Edwards

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
You should have received a copy of the GNU General Public License
along with this program.  If not, see <http://www.gnu.org/licenses/>.
*/

#pragma once

/* key matrix size */
#define MATRIX_ROWS 3
#define MATRIX_COLS 4

#define MATRIX_ROW_PINS { GP28, GP29, GP0 }
#define MATRIX_COL_PINS { GP4, GP1, GP2, GP27 } // GP27 is hyjacked joystick y pin.

#define DYNAMIC_KEYMAP_LAYER_COUNT 16

/* COL2ROW for me, ROW2COL*/
#define DIODE_DIRECTION COL2ROW

//#define ENCODER_MAP_KEY_DELAY 10

#define ENCODER_COUNT 1
#define ENCODER_RESOLUTION 2
#define ENCODER_DIRECTION_FLIP
#define TAP_CODE_DELAY 10

/* LED matrix*/
#define WS2812_DI_PIN GP3
//6 for basic, 10 for radio one
#define RGB_MATRIX_LED_COUNT 7
//Key 2. For accurate animations I need it in center of { 0..224, 0..64 }
#define RGB_MATRIX_CENTER { 2, 1 }

#define ENABLE_RGB_MATRIX_ALPHAS_MODS
#define ENABLE_RGB_MATRIX_GRADIENT_UP_DOWN
#define ENABLE_RGB_MATRIX_GRADIENT_LEFT_RIGHT
#define ENABLE_RGB_MATRIX_BREATHING
#define ENABLE_RGB_MATRIX_BAND_SAT
#define ENABLE_RGB_MATRIX_BAND_VAL
#define ENABLE_RGB_MATRIX_BAND_PINWHEEL_SAT
#define ENABLE_RGB_MATRIX_BAND_PINWHEEL_VAL
#define ENABLE_RGB_MATRIX_BAND_SPIRAL_SAT
#define ENABLE_RGB_MATRIX_BAND_SPIRAL_VAL
#define ENABLE_RGB_MATRIX_CYCLE_ALL	Enables
#define ENABLE_RGB_MATRIX_CYCLE_LEFT_RIGHT
#define ENABLE_RGB_MATRIX_CYCLE_UP_DOWN
#define ENABLE_RGB_MATRIX_RAINBOW_MOVING_CHEVRON
#define ENABLE_RGB_MATRIX_CYCLE_OUT_IN
#define ENABLE_RGB_MATRIX_CYCLE_OUT_IN_DUAL
#define ENABLE_RGB_MATRIX_CYCLE_PINWHEEL
#define ENABLE_RGB_MATRIX_CYCLE_SPIRAL
#define ENABLE_RGB_MATRIX_DUAL_BEACON
#define ENABLE_RGB_MATRIX_RAINBOW_BEACON
#define ENABLE_RGB_MATRIX_RAINBOW_PINWHEELS
#define ENABLE_RGB_MATRIX_FLOWER_BLOOMING
#define ENABLE_RGB_MATRIX_RAINDROPS
#define ENABLE_RGB_MATRIX_JELLYBEAN_RAINDROPS
#define ENABLE_RGB_MATRIX_HUE_BREATHING
#define ENABLE_RGB_MATRIX_HUE_PENDULUM
#define ENABLE_RGB_MATRIX_HUE_WAVE
#define ENABLE_RGB_MATRIX_PIXEL_FRACTAL
#define ENABLE_RGB_MATRIX_PIXEL_FLOW
#define ENABLE_RGB_MATRIX_PIXEL_RAIN
#define ENABLE_RGB_MATRIX_STARLIGHT	Enables
#define ENABLE_RGB_MATRIX_STARLIGHT_SMOOTH
#define ENABLE_RGB_MATRIX_STARLIGHT_DUAL_HUE
#define ENABLE_RGB_MATRIX_STARLIGHT_DUAL_SAT
#define ENABLE_RGB_MATRIX_RIVERFLOW

#define ENABLE_RGB_MATRIX_TYPING_HEATMAP
#define ENABLE_RGB_MATRIX_DIGITAL_RAIN

// These require additional memory
#define ENABLE_RGB_MATRIX_SOLID_REACTIVE_SIMPLE
#define ENABLE_RGB_MATRIX_SOLID_REACTIVE
#define ENABLE_RGB_MATRIX_SOLID_REACTIVE_WIDE
#define ENABLE_RGB_MATRIX_SOLID_REACTIVE_MULTIWIDE
#define ENABLE_RGB_MATRIX_SOLID_REACTIVE_CROSS
#define ENABLE_RGB_MATRIX_SOLID_REACTIVE_MULTICROSS
#define ENABLE_RGB_MATRIX_SOLID_REACTIVE_NEXUS
#define ENABLE_RGB_MATRIX_SOLID_REACTIVE_MULTINEXUS
#define ENABLE_RGB_MATRIX_SPLASH
#define ENABLE_RGB_MATRIX_MULTISPLASH
#define ENABLE_RGB_MATRIX_SOLID_SPLASH
#define ENABLE_RGB_MATRIX_SOLID_MULTISPLASH

// disable backlight when USB suspended (sleep/hibernate/shutdown)
#define RGB_MATRIX_SLEEP

// 5 minute timeout in milliseconds
#define RGB_MATRIX_TIMEOUT 300000

/* Single Neopixel, 2 LED lines not supported in QMK*/

/* Single RGB (IDK why Xaio RP2040 has both)*/
#define INDICATOR_RED GP17
#define INDICATOR_GREEN GP16
#define INDICATOR_BLUE GP25

#define I2C_DRIVER I2CD1
#define I2C1_SDA_PIN GP6
#define I2C1_SCL_PIN GP7

#define OLED_BRIGHTNESS 128
#define OLED_DISPLAY_128X64

#define QP_OFFSET_X 0
#define QP_OFFSET_Y 0
#define QP_WIDTH 128
#define QP_HEIGHT 64


// The size of the "fake" EEPROM exposed to your code
#define WEAR_LEVELING_LOGICAL_SIZE 8192
#define WEAR_LEVELING_BACKING_SIZE 16384

// Timeout configuration, default 30000 (30 seconds). 0 = No timeout.
#define QUANTUM_PAINTER_DISPLAY_TIMEOUT 30000

#define QUANTUM_PAINTER_NUM_IMAGES 13


// Min 0, max 32
//#define JOYSTICK_BUTTON_COUNT 1
// Min 0, max 6: X, Y, Z, Rx, Ry, Rz
//#define JOYSTICK_AXIS_COUNT 2
// Min 8, max 16
//#define JOYSTICK_AXIS_RESOLUTION 10

//#define ANALOG_JOYSTICK_X_AXIS_PIN GP26
//#define ANALOG_JOYSTICK_Y_AXIS_PIN GP27

//Left trigger
#define BOOTMAGIC_ROW 0
#define BOOTMAGIC_COLUMN 0

//#undef NO_PRINT
//#undef NO_DEBUG

//DFU only, RP2040 has UF2
//#define QMK_LED GP3

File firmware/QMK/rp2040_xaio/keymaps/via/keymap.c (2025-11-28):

/* Copyright 2025 Asher Edwards
 *
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
 * You should have received a copy of the GNU General Public License
 * along with this program.  If not, see <http://www.gnu.org/licenses/>.
 */
#include QMK_KEYBOARD_H

#include <string.h>
#include "media/fonts/thintel15.qff.h"
#include "gui.c"
#include "utils/settings.h"
#include "utils/keyname_map.h"

enum my_keycodes {
  LAYR_CHNG_TGGL = SAFE_RANGE,
};

enum layer_names {
    L0,
    L1,
    L2,
    L3,
    L4,
    L5,
    L6,
    L7,
    L8,
    L9,
    L10,
    L11,
    L12,
    L13,
    L14,
    L15
};

// --- Globals ---
bool layer_change_toggle = false;

// --- Optimization: Track state to prevent unnecessary refreshes ---

static uint8_t last_rgb_mode = 255;

const uint16_t PROGMEM keymaps[][MATRIX_ROWS][MATRIX_COLS] = {

  /* Keymap 0: Basic layer
  *
  *                 .------------.             .------------.                               
  *    _____________|   MS_BTN1  |_____________|  MS_BTN2   |____________ 
  *  /              '------------'             '------------'    MS_WHLU  \
  * |                                                              _  _    |
  * |   Joystick                                                =        = |
  * |    .-------.    .-----------.-----------.-----------.   =            =
  * |  /    _ _    \  |  MS_WHLL  |   MS_UP   |  MS_WHLR  |  =              =
  * | .  .''   ''.  . |           |           |           |  =LAYR_CHNG_TGGL=
  * | | (    K    ) | |-----------+-----------+-----------|   =            =
  * | '  '.._ _..'  ' |  MS_LEFT  |  MS_DOWN  |  MS_RGHT  |     =        = |
  * |  \           /  |           |           |           |        ~  ~    |
  * '    '-------'    '-----------'-----------'-----------'       MS_WHLD  '
  *  \                                                                    /
  *    `-- .________________________________________________________. --'
  */
  [L0] = LAYOUT(
      MS_BTN1, MS_UP,   MS_BTN2,   MS_WHLU, \
      MS_WHLL, MS_DOWN,   MS_WHLR,   MS_WHLD, \
      KC_K, MS_LEFT,   MS_RGHT,   LAYR_CHNG_TGGL
  ),
  [L1] = LAYOUT(
      KC_TRNS, KC_TRNS, KC_TRNS , KC_TRNS, \
      KC_TRNS, KC_TRNS, KC_TRNS, KC_TRNS, \
      KC_TRNS, KC_TRNS, KC_TRNS, LAYR_CHNG_TGGL
  ),
  [L2] = LAYOUT(
      KC_TRNS, KC_TRNS, KC_TRNS , KC_TRNS, \
      KC_TRNS, KC_TRNS, KC_TRNS, KC_TRNS, \
      KC_TRNS, KC_TRNS, KC_TRNS, LAYR_CHNG_TGGL
  ),
  [L3] = LAYOUT(
      KC_TRNS, KC_TRNS, KC_TRNS , KC_TRNS, \
      KC_TRNS, KC_TRNS, KC_TRNS, KC_TRNS, \
      KC_TRNS, KC_TRNS, KC_TRNS, LAYR_CHNG_TGGL
  ),
  [L4] = LAYOUT(
      KC_TRNS, KC_TRNS, KC_TRNS , KC_TRNS, \
      KC_TRNS, KC_TRNS, KC_TRNS, KC_TRNS, \
      KC_TRNS, KC_TRNS, KC_TRNS, LAYR_CHNG_TGGL
  ),
  [L5] = LAYOUT(
      KC_TRNS, KC_TRNS, KC_TRNS , KC_TRNS, \
      KC_TRNS, KC_TRNS, KC_TRNS, KC_TRNS, \
      KC_TRNS, KC_TRNS, KC_TRNS, LAYR_CHNG_TGGL
  ),
  [L6] = LAYOUT(
      KC_TRNS, KC_TRNS, KC_TRNS , KC_TRNS, \
      KC_TRNS, KC_TRNS, KC_TRNS, KC_TRNS, \
      KC_TRNS, KC_TRNS, KC_TRNS, LAYR_CHNG_TGGL
  ),
  [L7] = LAYOUT(
      KC_TRNS, KC_TRNS, KC_TRNS , KC_TRNS, \
      KC_TRNS, KC_TRNS, KC_TRNS, KC_TRNS, \
      KC_TRNS, KC_TRNS, KC_TRNS, LAYR_CHNG_TGGL
  ),
  [L8] = LAYOUT(
      KC_TRNS, KC_TRNS, KC_TRNS , KC_TRNS, \
      KC_TRNS, KC_TRNS, KC_TRNS, KC_TRNS, \
      KC_TRNS, KC_TRNS, KC_TRNS, LAYR_CHNG_TGGL
  ),
  [L9] = LAYOUT(
      KC_TRNS, KC_TRNS, KC_TRNS , KC_TRNS, \
      KC_TRNS, KC_TRNS, KC_TRNS, KC_TRNS, \
      KC_TRNS, KC_TRNS, KC_TRNS, LAYR_CHNG_TGGL
  ),
  [L10] = LAYOUT(
      KC_TRNS, KC_TRNS, KC_TRNS , KC_TRNS, \
      KC_TRNS, KC_TRNS, KC_TRNS, KC_TRNS, \
      KC_TRNS, KC_TRNS, KC_TRNS, LAYR_CHNG_TGGL
  ),
  [L11] = LAYOUT(
      KC_TRNS, KC_TRNS, KC_TRNS , KC_TRNS, \
      KC_TRNS, KC_TRNS, KC_TRNS, KC_TRNS, \
      KC_TRNS, KC_TRNS, KC_TRNS, LAYR_CHNG_TGGL
  ),
  [L12] = LAYOUT(
      KC_TRNS, KC_TRNS, KC_TRNS , KC_TRNS, \
      KC_TRNS, KC_TRNS, KC_TRNS, KC_TRNS, \
      KC_TRNS, KC_TRNS, KC_TRNS, LAYR_CHNG_TGGL
  ),
  [L13] = LAYOUT(
      KC_TRNS, KC_TRNS, KC_TRNS , KC_TRNS, \
      KC_TRNS, KC_TRNS, KC_TRNS, KC_TRNS, \
      KC_TRNS, KC_TRNS, KC_TRNS, LAYR_CHNG_TGGL
  ),
  [L14] = LAYOUT(
      KC_TRNS, KC_TRNS, KC_TRNS , KC_TRNS, \
      KC_TRNS, KC_TRNS, KC_TRNS, KC_TRNS, \
      KC_TRNS, KC_TRNS, KC_TRNS, LAYR_CHNG_TGGL
  ),
  [L15] = LAYOUT(
      QK_BOOT, KC_TRNS, KC_TRNS, KC_TRNS, \
      KC_TRNS, KC_TRNS, KC_TRNS, KC_TRNS, \
      KC_TRNS, KC_TRNS, KC_TRNS, LAYR_CHNG_TGGL
  )

};

// Cannot do encoder map with VIA, because the map overrides our custom menu handling.
// There will be two extra keys in VIA because of this.

void keyboard_post_init_user(void) {

    keyname_map_init(); // Zero out RAM
    custom_eeprom_load(); // Load from Flash

    layer_change_toggle = false;
    update_oled = true;

    // ---- DEFINE KEYMAP DATA ----
    // If Layer 0 has no name, assume this is a fresh install and apply defaults.
    // We check the first character of the name string.
    if (keyname_map_get_layer_name(0)[0] == '\0') {
        
        // ---- DEFINE DEFAULTS (Only runs once) ----
        
        // Layer 0: Base Layer for Mouse
        keyname_map[0] = (LayerData_t){
            .name = "Mouse",
            .imageName = "",
            .lightingEffect = 5,//Breathing
            .effectSpeed = 128,//half speed
            .color = { .h = 128, .s = 255, .v = 128 },
            .keys = {
                {.name = "LClk", .imageName = "left_trig"},
                {.name = "Up", .imageName = "up"},
                {.name = "RClk", .imageName = "right_trig"},
                {.name = "WHLU", .imageName = "u_point"},
                {.name = "WHLL", .imageName = "l_point"},
                {.name = "Down", .imageName = "down"},
                {.name = "WHLR", .imageName = "r_point"},
                {.name = "WHLD", .imageName = "d_point"},
                {.name = "K", .imageName = ""},
                {.name = "Left", .imageName = "left"},
                {.name = "Right", .imageName = "right"},
                {.name = "CHGN", .imageName = ""}
            }
        };
        
        // Layer 15
        keyname_map[15] = (LayerData_t){
            .name = "Misc",
            .imageName = "",
            .lightingEffect = 0,//Disable
            .keys = {
                { .name = "Boot", .imageName = "", .color = { .h = 0, .s = 255, .v = 255 } }
            }
        };
        // Save
        mark_layer_dirty(0);
        mark_layer_dirty(15);
        save_requested = true;
    }

    gui_init();//font_arial_12 option??

}
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

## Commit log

2025-02-12 Add draft schematics for all the input sources
    [Analog Input.kicad_sch, Battery Management.kicad_sch, JoyKey.kicad_sch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]
2025-02-14 Updated matrix for encoder
    I swapped the common pin on the encoder to be connected to the columns since my scanning will be col2row. I don't want the common to go through two diodes!
    [Matrix.kicad_sch]
2025-02-14 Simplified analog input schematic and added proper joystick symbol
    [Analog Input.kicad_sch]
2025-02-14 Rearranged LEDs and switched to SK6812 mini -e
    These are reverse mount RGB LEDs that I think would be better to use than the ws2812 leds
    [LEDs.kicad_sch]
2025-02-14 Added battery management
    This is the placeholder circuit taken from one of my robot designs. I need to find cheaper and simpler chips. I do NOT need batter power path management due to the xiao being the source and drain at 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
    [Battery Management.kicad_sch]
2025-02-14 Updated top level schem arrangement
    [JoyKey.kicad_sch]
2025-02-14 Redrawing hierarchical sheet shapes
    [JoyKey.kicad_sch]
2025-02-14 Assigned footprints for batt management
    [Battery Management.kicad_sch]
2025-02-14 Added netties to matrix for encoder inputs
    I want the nets to be separate in different areas, so I have added netties
    [Matrix.kicad_sch]
2025-02-14 Fixed bug w reverse orientation of LEDs
    [LEDs.kicad_sch]
2025-02-14 Replaced 2 keys with headers for top Triggers
    Since there are not right angle keys (just buttons), I will use normal keys embedded in the case with wires soldering to the board
    [Matrix.kicad_sch]
2025-02-14 Updated SMD Resistor size to 0805
    I don't want to use small resistors on this project, too much of a hassle.
    [Battery Management.kicad_sch]
2025-02-14 Switched output diode to known model
    This is a schottkey diode that I have worked with before and I know its low dropout and quick reacting
    [Battery Management.kicad_sch]
2025-02-14 Fixed short between battery gate and ground
    [Battery Management.kicad_sch]
2025-02-14 Fixed ERC rules
    [JoyKey.kicad_sch]
2025-02-14 Updated Parts in PCB
    [JoyKey.kicad_pcb]
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2025-02-15 Updated Diode to SMD
    I don't want through holes because they take up too much space
    [Matrix.kicad_sch]
2025-02-15 Updated to not distinguished btw LEDs per element
    [LEDs.kicad_sch]
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2025-02-15 Updated display to proper one
    [JoyKey.kicad_pcb, JoyKey.kicad_sch]
2025-02-15 Added Mating Point to joystick schematic
    [Analog Input.kicad_sch]
2025-02-15 Finished main part layout
    [JoyKey.kicad_pcb]
2025-02-15 Re-arranged matrix to have L-shaped clusters
    Based on my horizontal layout I really have a 6*2 matrix, however the most switches for the least pins is actually a 4*3. So, I have to great creative with my routing to make it fit.
    [JoyKey.kicad_pcb, JoyKey.kicad_sch, Matrix.kicad_sch]
2025-02-15 Fixed Encoder on Matrix (again)
    I got it messed up, A and B should have separate power sources (columns) and common should go to the row. If I had vertical orientation I would have common be on the column and A and B on separate rows. Previous caused a short between columns that could cause ghosting.
    [JoyKey.kicad_pcb, Matrix.kicad_sch]
2025-02-15 Removed Display Mounting holes
    Annoying, and unneeded
    [JoyKey.kicad_pcb]
2025-02-16 Revert "Added netties to matrix for encoder inputs"
    [Matrix.kicad_sch]
2025-02-16 Adjusted Edge Cuts shape
    [JoyKey.kicad_pcb]
2025-02-16 Swapped Col1 and 2 for easier routing
    [JoyKey.kicad_sch]
2025-02-16 Finished Column routing and LED Data routing
    [JoyKey.kicad_pcb]
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2025-02-16 Swapped row pins for easier routing
    [JoyKey.kicad_sch]
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2025-02-16 Add Mating point GND to encoder
    [Analog Input.kicad_sch, JoyKey.kicad_pcb]
2025-02-16 Finished 3v3 and Diode routing
    [JoyKey.kicad_pcb]
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2025-02-16 Moved left joystick LED
    [JoyKey.kicad_pcb]
2025-02-16 Adjusted Edge Lights and increased board size to 100mm
    [JoyKey.kicad_pcb]
2025-02-16 Adjusted trigger switch position and LED strip header
    [JoyKey.kicad_pcb]
2025-02-16 Added custom DRC rule to exclude reverse mount edge clearance
    Its in the footprint that the pads are right next to the hole, and it doesn't matter if some copper is cut out.
    [JoyKey.kicad_pcb]
2025-02-16 Fixed some clearance issues
    [JoyKey.kicad_pcb]
2025-02-16 Add 2 mounting holes
    [JoyKey.kicad_pcb, JoyKey.kicad_sch]
2025-02-16 Added filleted lines and CAD export
    [JoyKey.kicad_pcb, JoyKey_pcb.step]
2025-02-16 Added Silkscreen name and author
    [JoyKey.kicad_pcb]
2025-02-17 Adjusted display to be in PCB center instead of keypad center
    It looks better now, originally I wanted the whole display to be centered for the whole device, but I think I may end up using the verticle encoder and having the pcb be the final shape
    [JoyKey.kicad_pcb, JoyKey_pcb.step, PS2 Joystick.step]
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2025-02-17 Added Accel and Gyro sensor
    [JoyKey.kicad_pcb, JoyKey.kicad_sch]
2025-02-18 Adjusted silkscreen text and added custom font
    [JoyKey.kicad_pcb]
2025-02-20 Added 2 extra LEDs
    [JoyKey.kicad_pcb, LEDs.kicad_sch]
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2025-02-20 Switched encoder to Alps EC12
    I wanted something shorter and that didn't have a metal screw post. I do loose out on the switch though, which I've exposed via a separate header
    [Analog Input.kicad_sch, JoyKey.kicad_pcb, JoyKey.kicad_sch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]
2025-02-21 Updated Battery Management to Adafruit Feather system
    I wanted to use a proven design that was low cost, and this seemed the best option. Only modification is removing the 5v input to the 3.3v regulator so that I don't have two regulators fighting
    [Battery Management.kicad_sch, JoyKey.kicad_sch]
2025-02-21 Added JST mating point to connector
    [Battery Management.kicad_sch]
2025-02-21 Switched out accel+gyro unit
    [JoyKey.kicad_sch]
2025-02-21 Added Complete battery management layout
    [JoyKey.kicad_pcb]
2025-02-21 Fixed some silkscreen errors
    [JoyKey.kicad_pcb]
2025-02-21 Changed footprint for Gyro to avoid copper clearance issues
    [JoyKey.kicad_sch]
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2025-03-12 Small tweaks to PCB
    [Analog Input.kicad_sch, Battery Management.kicad_sch, JoyKey.kicad_pcb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]
2025-03-12 Updated CAD model for more ergonomic position
    [Case - JoyKey Case.step, Case - JoyKey lid.step, Main Assembly.step]
2025-03-15 Reverse polarity of JST to match Adafruit Battery polarity
    It was an issue I had missed in my review
    [Battery Management.kicad_sch, JoyKey.kicad_pcb]
2025-03-15 Updated BOM with LCSC parts
    [Battery Management.kicad_sch, JoyKey.kicad_pcb, JoyKey.kicad_sch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]
2025-03-17 Added Positive and Negative symbols to JST battery plug
    [JoyKey.kicad_pcb]
2025-03-17 Switched encoder to Alps SRBE110301 in sch
    [Analog Input.kicad_sch, JoyKey.kicad_sch, Matrix.kicad_sch]
2025-03-17 Updated to Vertical matrix orientation of encoder
    [Matrix.kicad_sch]
2025-03-17 Fixed all routing and added footprint of encoder
    [JoyKey.kicad_pcb]
2025-03-17 Fixed Encoder Silkscreen
    [JoyKey.kicad_pcb]
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2025-03-17 fix DRC errors
    [JoyKey.kicad_pcb]
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2025-06-29 Add reverse mount for side encoder to simplifiy assembly
    Now, if you want, you can get ALL SMD components on one side! I still prefer the encoder to be put on the top side because it is more central to the whole body, but of course, 2 sided assembly has its costs and I wanted to minimize that.
    [Analog Input.kicad_sch, JoyKey.kicad_pcb, bom.csv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]
2025-06-30 Add decoupling capacitors to LEDs
    There isn't much to loose from this
    [JoyKey.kicad_pcb, LEDs.kicad_sch, bom.csv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]
2025-06-30 Added larger battery cavity in CAD
    [Case - JoyKey Case.step, Case - JoyKey lid.step, JoyKey_pcb.step]
2025-07-11 fixed finger grips, overlaps, and magic numbers
    [Case - JoyKey Case.step, Case - JoyKey lid.step]
2025-07-11 fix screen holder dimensions
    [Case - JoyKey Case.step, Case - JoyKey lid.step]
2025-07-11 swap screw & heatset sides
    [Case - JoyKey Case.step, Case - JoyKey lid.step]
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2025-07-11 fixed assembly and encoder dial side
    [Case - JoyKey Case.step, Case - JoyKey lid.step]
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2025-07-14 fix screen and key gap
    [Case - Dial.step, Case - JoyKey Case.step, Case - JoyKey lid.step]
2025-07-14 swap encoder wall w lid
    Now the lid comes on top of the encoder dial to enclose it
    [Case - JoyKey Case.step, Case - JoyKey lid.step]
2025-07-14 Fix dial & battery compartment
    [Case - Dial.step, Case - JoyKey Case.step, Case - JoyKey lid.step]
2025-07-14 make bottom fillets print nicer with chamfers
    [Case - Dial.step, Case - JoyKey Case.step, Case - JoyKey lid.step]
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2025-07-16 changed body shape to be more joycon like
    [Case - Dial.step, Case - JoyKey Case.step, Case - JoyKey lid.step]
2025-07-16 fix dial and mount
    [Case - Dial.step, Case - JoyKey Case.step, Case - JoyKey lid.step]
2025-07-16 cutout for capacitor, increase gap for screen wires
    [Case - Dial.step, Case - JoyKey Case.step, Case - JoyKey lid.step]
2025-07-16 made dial clickable again and increase finger space
    [Case - Dial.step, Case - JoyKey Case.step, Case - JoyKey lid.step]
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2025-07-16 fixed corrupted files
    [Case - Dial.step, Case - JoyKey Case.step, Case - JoyKey lid.step]
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2025-07-17 temporary code, not working
    [config.h, keymap.c]
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2025-07-26 Change default 0 layer to mouse actions
    Boot reset is also optional, I have configured it in VIA for layer 15 but that isn't flashed by default.
    [keymap.c]
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2025-09-08 Add layer and key names structure
    Haven't tested, probably won't work
    [keymap.c]
2025-11-23 Fixed bugs, added boot button, Adjusted colors
    [keymap.c]
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2025-11-23 Fix keycode for latest FW
    [keymap.c]
2025-11-24 Bug fixes with setting update, LED index
    [keymap.c]
2025-11-26 Standardized command ids, fixed render bugs
    [keymap.c]
2025-11-26 Bug fix with live update oled
    [keymap.c]
2025-11-26 Faulty LED fix, 1 less
    [config.h, keymap.c]
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2025-11-28 Fix image loading overflow
    A few weren't being unloaded causing them to not render when layers were switched. This is dynamic now and fits everything else.

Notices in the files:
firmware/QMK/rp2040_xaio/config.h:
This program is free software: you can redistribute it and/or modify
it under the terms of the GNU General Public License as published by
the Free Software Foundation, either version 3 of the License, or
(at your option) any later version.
